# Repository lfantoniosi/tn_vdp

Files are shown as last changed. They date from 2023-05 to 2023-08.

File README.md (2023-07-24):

# TN VDP 

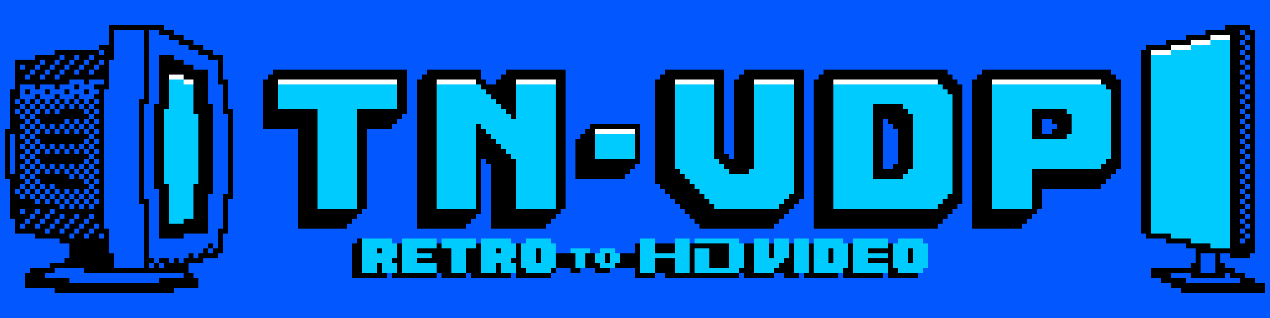
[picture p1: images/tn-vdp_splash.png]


# Latest updates:

## 2023-06-20: V3 Main Board with audio fix (Tang20k only)

New V3 board with audio fix has been submitted. Check the kicad folder for gerbers. It requires few new components that you can read on the board. Pretty simple: 10uf capacitor and an optional cinch connector. I will not be updating the BOM lists. WIP project. For a 9958 socket, turn off GromClk (Jumper 3). Leave CpuClk on (Jumper4).

## 2023-06-20: V9958 Socket (V3 Tang20K)

The V9958 drop-in socket (SDIP-64) has been submitted. Check the kicad folder. Code has been improved for Omega MSX compatibility. SDIP pin header are hard to find. Check AliExpress for **"1.778mm Pitch Single Row Male Round Pin Header"**. Not including links they aren't persistent. You need a V3 main board as well for the Tang20K. 

**Note** My Omega MSX has the RAM expansion module and I found out it has incompatiblity with the Tang (seems to be too noisy). If you get issues with IDE controllers, try removing some RAM chips from higher banks. I left my Omega with only 2MB. It's not a PSU problem but rather a routing issue that plagues the Omega for some time.

# Project details
 
## Tang Nano 9K TMS9118A VDP

This project recreates the TMS9118A (and its TMS9928A/TMS9929A
variants) in FPGA using the over the counter Sipeed's Tang Nano 9K
board plus a designed set of boards to be stacked on top where the
TMS9118 was located.

TN VDP v1 uses
[Matthew Haggerty's F18A core](https://github.com/dnotq/f18a), which
is completely compatible with the original Texas Instruments VDP, but
adds
[additional video modes, sprites and color capabilities](https://dnotq.io/f18a/intro.html).

The bitstream file is [here](fpga/tn_vdp_v1/impl/pnr/tn_vdp.fs)

## Version 2.0

The new version supports audio over HDMI. There is no more VGA output. You'll need to pull the pre-amplified audio from somewhere in the computer and connect the **AUDIO** pin on the tn-vdp socket. **MODE1** is not used for TMS9918 cores.

This requires the v2 board sets as well the v2 bitstream (socket board + mainboard). See below gerber files.

There are 2 bitstreams for v2:

[TMS9918](fpga/tn_vdp_v2_v9918/impl/pnr/tn_vdp.fs)

## V9958 32KB VRAM

There is a new core for the v2 boards implemented from ESE-MSX3. The bitstream can be used on the same v2 board sets for the TMS9918:

[V9958](fpga/tn_vdp_v2_v9958/impl/pnr/tn_vdp_v9958.fs)

But for the V9958 you need to pull the A1 address line from somewhere in the computer and connect to pin **MODE1** on the socket to use the full capabilites of the V9958.

## V9958 128KB VRAM: Tang Nano 20K

The v3 of the fpga code and mainboard is for use on a Tang Nano 20K only. There are no other versions for Tang Nano 20K other than V9958 128K. If you need a 9918 use the Tang Nano 9K instead. The socket for the TMS9118 is the same from v2. A socket for a V9958 replacement is in the works.

See instructions below for programming it.

**Note** The gromclk signal has been retired from V9958 128K (no MSX ever uses it). So instead turning this jumper on puts the VDP in no-wait mode, full speed 27Mhz. Turning off it makes the VDP at normal speed (for VDP commands).

## NABU PC Floppy images

Bootable 80 colums for NABU PC CP/M 3 images can be downloaded here (flux and HxC2001): 

[NABU PC images](https://drive.google.com/file/d/1nU48-01ozhA_n-ZHN1SCNINqFqhcBxUN/view?usp=sharing)

## Gerber files

The gerber files can be located inside each KiCad project:

### V1 Boards
[MainBoard for NABU](kicad/tn_vdp_v1_slim/gerber.zip)

[MainBoard for TI-99/4A (FAT)](kicad/tn_vdp_v1_fat/gerber.zip)

[VGA breakout](kicad/tn_vdp_v1_vga/gerber)

[Compact board using SMD components](kicad/tn9k_f18a_compact/gerber.zip)
See the [separate README](kicad/tn9k_f18a_compact/README.md) for BOM ipand additional information.

The VGA module is optional, only if you want VGA output.

### V2 Boards

[MainBoard v2](kicad/tn_vdp_v2_board/gerber.zip)

[Socket v2](kicad/tn_vdp_v2_socket/gerber.zip)

### V3 Boards: Tang Nano 20K ONLY!

[MainBoard v3](kicad/tn_vdp_v3_board/gerber.zip)

[Socket v2](kicad/tn_vdp_v2_socket/gerber.zip) (same TMS9918 socket as v2)

## Gowin IDE
Follow this link to install the Gowin's IDE:

**Note: The code can be built and programmed using the latest Education Version 1.9.8.11 - The Education EDA does not require a license. DO NOT USE THE BETA EDA/PROGRAMMER.**

[IDE Installation](https://wiki.sipeed.com/hardware/en/tang/Tang-Nano-Doc/install-the-ide.html)

The FPGA series is GW1NR and the Device is GW1NR-9C. Use Embedded Flash Mode for permanent programming. Make sure the bitstream is set to Load Rate of 25Mhz (or higher) in the Project -> Configuration -> BitStream: Loading Rate (MHZ). The maximum for this device is 25 Mhz.

## Programming the FPGA

**Gowin Programmer**
Together Gowin IDE you find the programmer or you can install the programmer stand alone. Check the Gowin IDE instructions

**openFPGALoader**
Alternatively you can use the openFPGALoader but it requires changing the FTDI drivers through zadig. Follow the official page for instructions

The [openFPGALoader](https://github.com/trabucayre/openFPGALoader)
tool can be used to program the FPGA from the command line.

```
sudo openFPGALoader -b tangnano9k tn_vdp.fs
```

## Standalone test

The board has a standalone boot screen when you connect it to the USB-C and HDMI only. This will tell the FPGA has been programmed with success.

The v3 Tang Nano 20K has no standalone boot screen.

## Building:

The Tang Nano 9K board can be purchased on AliExpress or ebay.

The boards gerber files are inside each kicad project gerber folders.

## V1 BOM

The BOM for the NABU and FAT v1 variants can be found here [DigiKey BOM](https://www.digikey.ca/short/2t98zrjw)

Or transcribed here
```
Qty | Part Number                | Description
----+----------------------------+----------------------------------
1x  | 123-A-HDF15A-KG-TAXB-ND    | CONN D-SUB HD RCPT 15P R/A SLDR
3x  | 123-AR20-HZL-TT-ND         | CONN IC DIP SOCKET 20POS TIN
2x  | S7022-ND                   | CONN HDR 24POS 0.1 TIN PCB
1x  | 449-KT04RTH-ND             | SWITCH SLIDE DIP 4POS 25MA 24V
3x  | 296-8503-5-ND              | IC TXRX NON-INVERT 3.6V 20DIP
3x  | 1109PHCT-ND CAP            | CER 0.1UF 50V X7R AXIAL
2x  | 2057-PH2RA-16-UA-ND        | CONN HEADER R/A 16POS 2.54MM
2x  | A835AR-ND                  | CONN HDR DIP POST 20POS GOLD
1x  | ED3048-5-ND                | CONN IC DIP SOCKET 40POS TIN
1x  | 2057-ICM-640-1-GT-HT-ND    | MACHINE PIN SOCKET, IC, DIP, 40P
1x  | 1528-5294-ND               | GPIO RIBBON CABLE 2X10 IDC CABLE
3x  | CF14JT2K20CT-ND            | RES 2.2K OHM 5% 1/4W AXIAL
2x  | CF14JT47R0CT-ND            | RES 47 OHM 5% 1/4W AXIAL
3x  | CF14JT4K70CT-ND            | RES 4.7K OHM 5% 1/4W AXIAL
3x  | CF14JT1K00CT-ND            | RES 1K OHM 5% 1/4W AXIAL
3x  | F14JT470RCT-ND             | RES 470 OHM 5% 1/4W AXIAL
1x  | 497-4547-1-ND              | DIODE SCHOTTKY 20V 1A DO41
```
**Notes:**

1) CONN HDR DIP POST 20POS GOLD: It is expensive on DigiKey but it can be sourced elsewhere cheaper, even Amazon.
2) GPIO RIBBON CABLE 2X10 IDC CABLE : It was supposed to be 2x8 but is out of stock. The 2x10 just works. Or build your own.
3) The capacitors need to be soldered manually on the bottom of each IC's. There are no pads for them to reduce the size of the board. See back.jpg photo for reference under images folder.
4) There are 2 DIP 40 sockets in this list: one machined other normal. The machined socket you will use to connect the board on top, thus protecting the pins. The machined pins for the board will connect easily to a machined socket. Then you stack this machined socked over the normal one (notice little force is necessary), and then finally you stack them at the NABU PC's TMS9118 socket. This will protect both the NABU and the tn_vdp pins.

# V2 BOM
```
Qty | Part Number                | Description
----+----------------------------+----------------------------------
3x  | 123-AR20-HZL-TT-ND         | CONN IC DIP SOCKET 20POS TIN
1x  | 2057-ICM-308-1-GT-HT-ND    | MACHINE PIN SOCKET, IC, DIP, 8P
3x  | 296-8503-5-ND              | IC TXRX NON-INVERT 3.6V 20DIP
4x  | BC1084CT-ND                | CAP CER 0.1UF 50V X7R RADIAL
1x  | 1528-5294-ND               | GPIO RIBBON CABLE 2X10 IDC CABLE
1x  | 497-4547-1-ND              | DIODE SCHOTTKY 20V 1A DO41
1x  | MCP3202-CI/P-ND            | IC ADC 12BIT SAR 8DIP
2x  | S7022-ND                   | CONN HDR 24POS 0.1 TIN PCB
2x  | A835AR-ND                  | CONN HDR DIP POST 20POS GOLD
4x  | 732-5301-ND                | CONN HEADER VERT 20POS 2.54MM 
1x  | 10129379-920001BLF-ND      | CONN HEADER R/A 20POS 2.54MM
4x  | S9000-ND                   | CONN JUMPER SHORTING TIN
```
**Notes:**

I find these header pins 2.54mm too expensive on DigiKey. I'd advise you to procure them on AliExpress, longer wait time but way cheaper. 

# V3 BOM

The V3 BOM is almost identically to V2 except that I added a trimmer for the audio and I returned with the DIP switch 4 pos:

```
Qty | Part Number                | Description
----+----------------------------+----------------------------------
1x  | 3339P-1-103LF              | TRIMMER 10K OHM 0.5W PC PIN TOP
1x  | 449-KT04RTH-ND             | SWITCH SLIDE DIP 4POS 25MA 24V
```

## Jumper Settings

These are the jumper. Closed means ON:
```
USR1 : SPR MAX - Turn it on for 32 sprites per line (9958 this puts 8 sprites for mode 0)
USR2 : SCANLIN - Turn it on for scanlines
USR3 : GROMCLK - Turn it on to have GROM CLOCK enabled, Disabling it puts CPUCLK on pin 37 (9128/29)
USR4 : CPUCLK  - Turn if on to have CPU CLOCK on pin 38 (9929/29 and 9128/29)
```

## Assembling Instructions

You shouldn't have problem assembling it as all components are labeled. Just remember the 2 pin strips for the TMS9118 slot goes under the board as well the 3 caps. Everything else it on the top side. I personally prefer soldering the female header on the FPGA board. Mind the orientation of the **DIP switch** as the image below.
```
1) solder the 3 DIP-20 sockets on top side
2) for each socket, solder one axial caps under the board connecting pins GND and VCC the back image below
3) solder the mini-switch on top side, mind hte numbering according to the text
4) solder the two male machine strips under the board (20 pins each strip)
5) solder the male pins that came with the Tang Nano 9K board on the top side of the board (24 pins each)
6) solder the 8x2 right angle header (optional for VGA)
6) solder the 2 female headers under the Tang Nano 9K board
7) install the 3 74VLC256 chips. Mind the half-moon orientation
7) plug the Tang Nano 9K on the male pins, mind the HDMI and UBS-C orientation as printed on the board
8) configure the dip-switches
```

## DIP switches
```
USR1 - 32 sprite per line (TMS9918), 8 sprites per line (V9958)
USR2 - scanlines
USR3 - pin 37: gromclk (on), cpuclk (off)
USR4 - pin 38: cpuclk (on), NC (off)

TMS9918A: (NABU-PC, CX5M)
USR3 - on
USR4 - on

TMS9928/29A
USR3 - on
USR4 - off

TMS9918
USR3 - on
USR4 - on

TMS9128/29
USR3 - off
USR4 - off
```

## V3 Programming

The Tang Nano 20K version is a bit more convoluted to install. We need to reconfigure the PLL nets.

First using the programmer flash this LITEX on the board:

[Tang Nano 20K LITEX](fpga/tn_vdp_v3_v9958/res/pnr/tang_nano_20k_litex.fs)

Disconnect and re-connect to your PC.

Go to device manager and change the properties for the USB Serial Port (COMxx) for your Tang Nano 20K (disconnect/reconnect the board and see wich one disappear to identify it). Change the Port Settings: Bits per second to 115200 and Apply.

Now you need a terminal application like Tera Term to connect to serial port.

Pressione Control-X Control-C and ENTER

You should see the LITE terminal, type:

```
pll_clk O0=50M
pll_clk O1=125M
pll_clk -s
```

After that you can just flash the v3 core from here:

[V9958 128K](fpga/tn_vdp_v3_v9918/impl/pnr/tn_vdp_v3_v9958.fs)

Now the board is ready to use.

## Images

Front of the board

You need to solder the capacitors under each IC's. I made this way to reduce the size of the board.

Back of the bard

And the final board stacked up. To avoid plugging the board inverted there are two labels on it: **USB-C SIDE** and **HDMI SIDE**. The orientation of the board towards the TMS9118 slot is the USB-C up (pin 1 of TMS9118). The TMS9118 pin number 1 and 40 are printed under it.

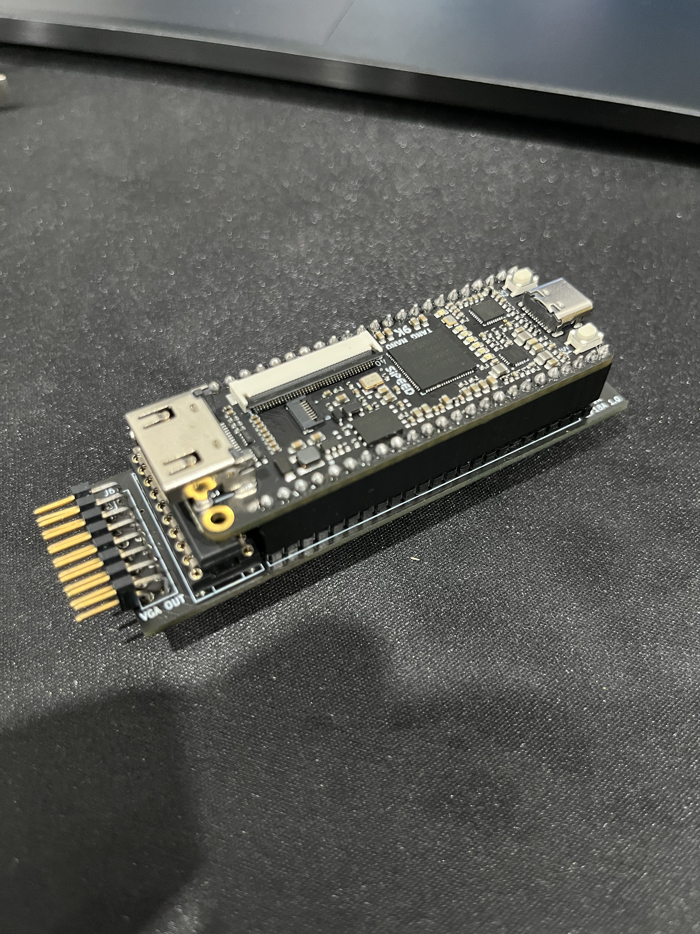
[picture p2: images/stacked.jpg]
Stacked


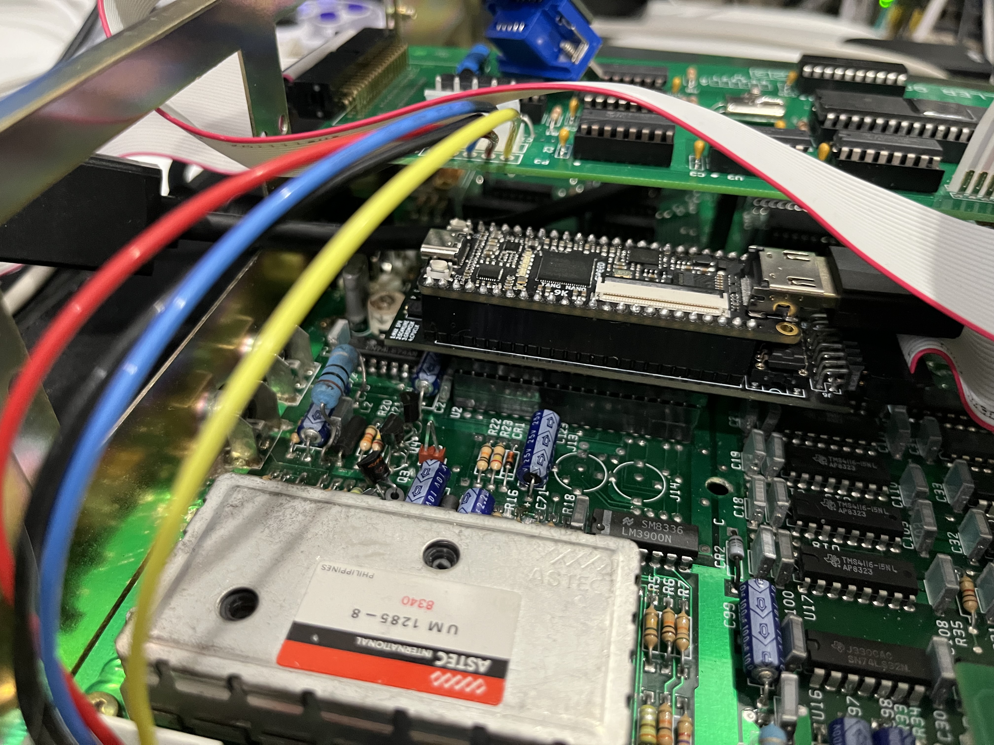
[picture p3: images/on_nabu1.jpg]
On Nabu 1


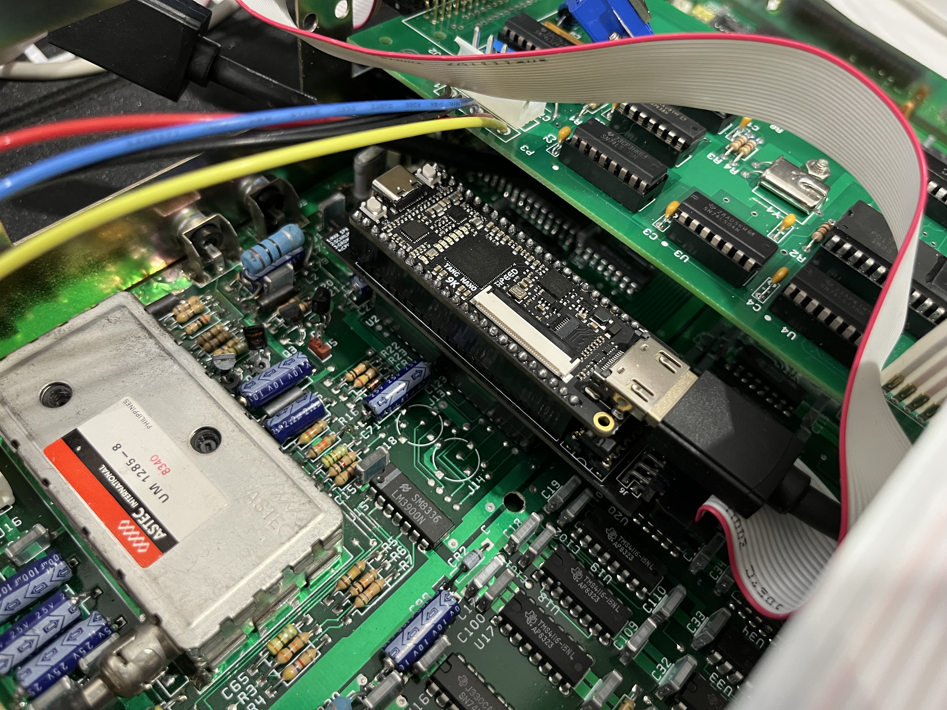
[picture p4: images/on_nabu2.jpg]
On Nabu 2


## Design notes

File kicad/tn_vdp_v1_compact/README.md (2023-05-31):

# TMS9918A compatible VDP based on Tang Nano 9k - Compact (SMD) version

This version is a compact variant of the tn_vdp_v1 board that directly
fits into the VDP socket of the TI-99/4A.  It uses SMD components and
has the same size as the Tang Nano 9k board.  It comes with a VGA
breakout connector that can be directly used if the space in the host
machine allows it, or be snapped off, mounted on a breakout panel on
the back of the host machine and be connected with a ribbon cable.

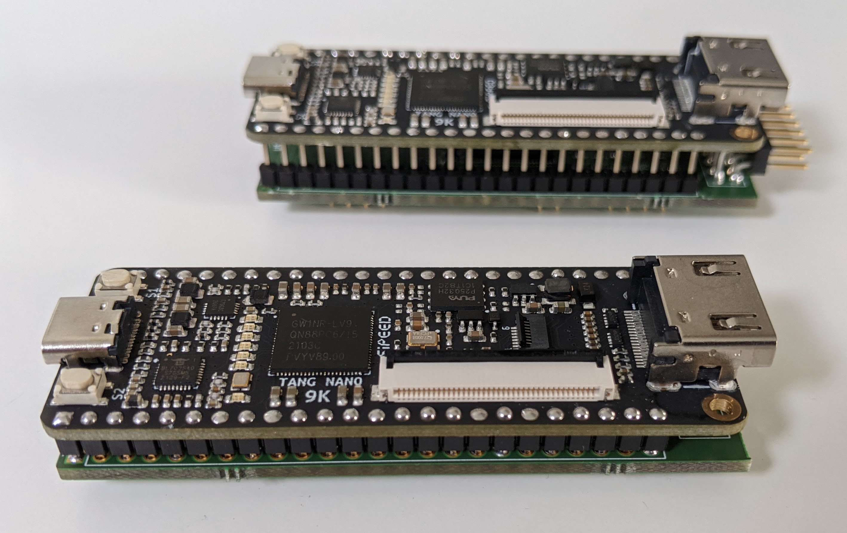
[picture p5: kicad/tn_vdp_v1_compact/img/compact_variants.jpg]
Two variants of the compact board

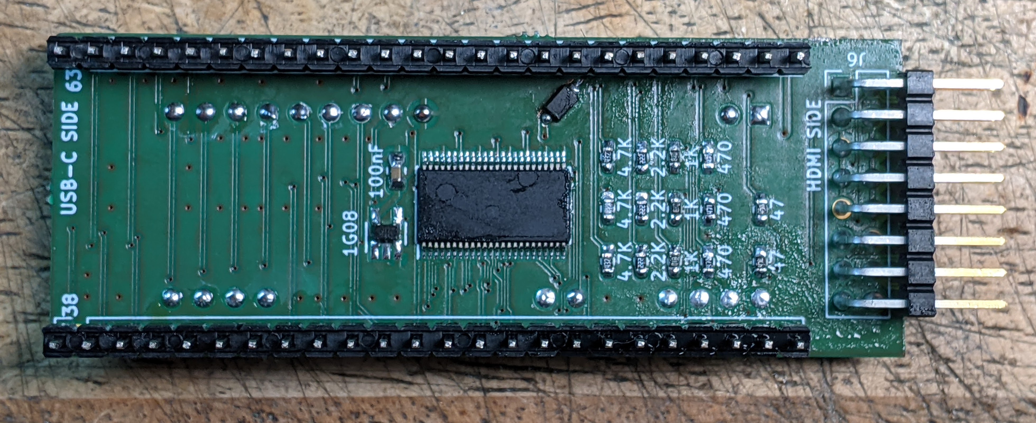
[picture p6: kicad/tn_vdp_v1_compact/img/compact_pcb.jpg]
Compact PCB


## BOM

|Item|Qty|Reference(s)|Value |Description |Part Number |Footprint|URL |
|----|---|---|---|---|---|---|---|
|1 |1  | |Tang Nano 9k|FPGA development board | | |https://wiki.sipeed.com/hardware/en/tang/Tang-Nano-9K/Nano-9K.html|
|2 |1  |U1 |1G08 |Single AND gate |SN74LVC1G08 |SOT-23-5 |http://www.ti.com/lit/sg/scyt129e/scyt129e.pdf |
|3 |1  |U4 |74LCX16245  |16 bit buffer |74LCX16245MTD |TSSOP-48 |https://www.onsemi.com/pdf/datasheet/mc74lcx16245-d.pdf |
|4 |1  |D1 |D_Schottky  |Schottky diode |MBR0530 |SOD-123  | |
|5 |3  |R1, R5, R9  |4.7K |Resistor SMD 0603 | |0603 | |
|6 |3  |R2, R6, R10 |2.2K |Resistor SMD 0603 | |0603 | |
|7 |3  |R3, R7, R11 |1K |Resistor SMD 0603 | |0603 | |
|8 |3  |R4, R8, R12 |470 |Resistor SMD 0603 | |0603 | |
|9 |2  |R13, R14 |47 |Resistor SMD 0603 | |0603 | |
|10  |1  |C1 |100nF |Capacitor SMD 0603 | |0603 | |
|11  |21 |J1 | |PCB pin Mill-Max |3157-0-00-15-00-00-03-0| | |
|12  |1  |J6 |VGA |Pin Header 2.54mm Horizontal 16pos |68021-116HLF | | |
|13  |1  |J2 |VGA |Ribbon cable 16 pin 2x8 solder to 2x8 IDC| | |https://de.aliexpress.com/item/1005004165880347.html |
|14  |1  |J5 |VGA |DB15HD connector, female | | | |

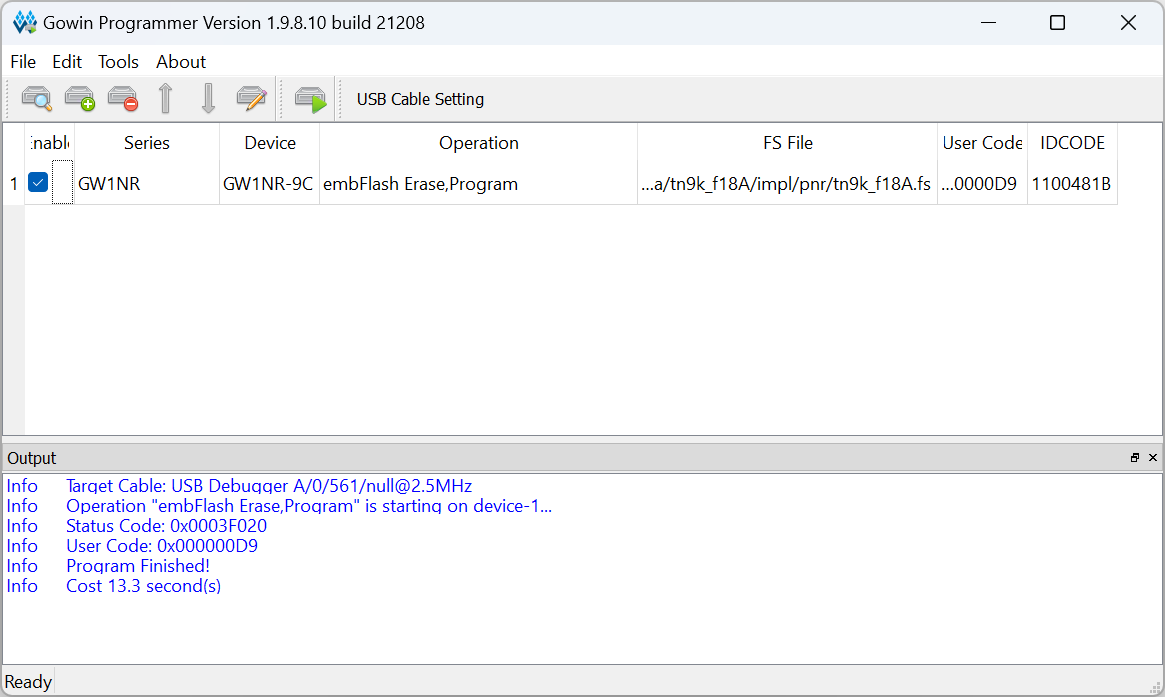
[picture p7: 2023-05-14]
images/programmer.png

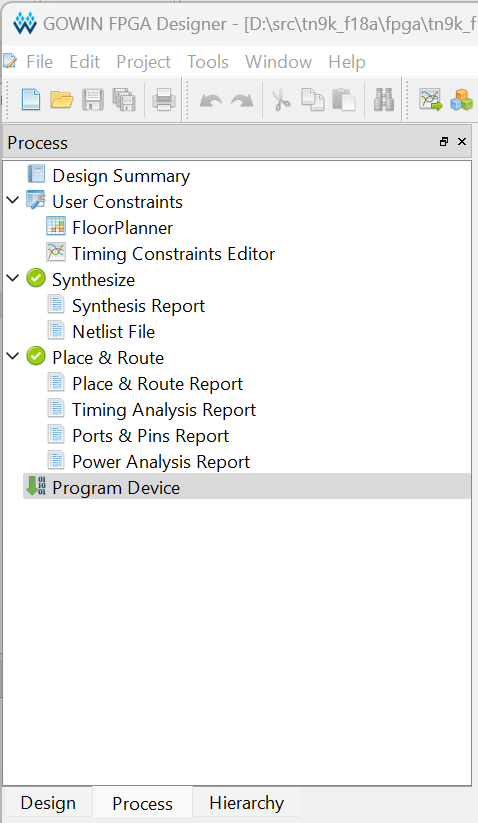
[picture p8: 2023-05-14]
images/program-device.png

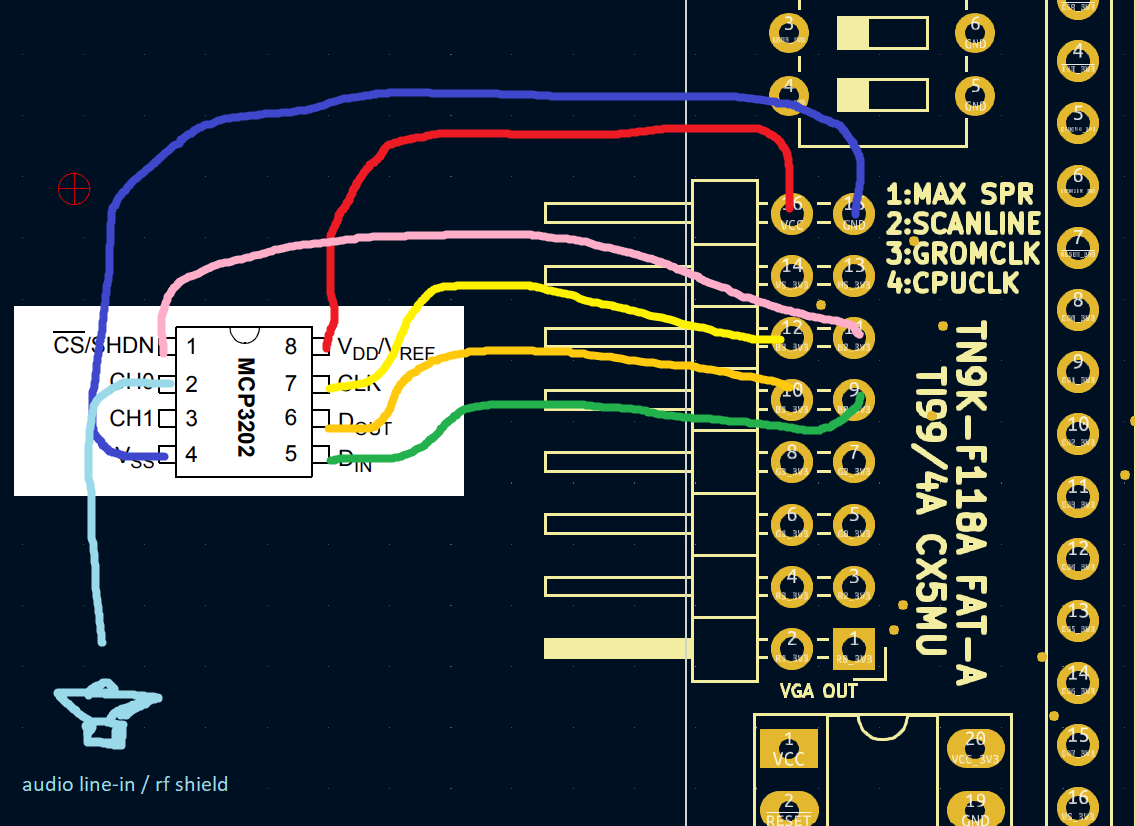
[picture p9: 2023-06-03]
images/audio_modification_fat_board.png

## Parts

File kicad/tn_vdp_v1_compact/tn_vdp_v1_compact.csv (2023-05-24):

Comment | Designator | Footprint | LCSC
100nF | C1 | Capacitor_SMD:C_0603_1608Metric_Pad1.08x0.95mm_HandSolder | C2857981
D_Schottky | D1 | Diode_SMD:D_SOD-123 | C2900723
VGA | J2,J6 | Connector_PinHeader_2.54mm:PinHeader_2x08_P2.54mm_Vertical
Tang Nano 9k | J3 | Connector_PinSocket_2.54mm:PinSocket_1x24_P2.54mm_Vertical
TN9k/2 | J4 | Connector_PinSocket_2.54mm:PinSocket_1x24_P2.54mm_Vertical
VGA | J5 | Connector_Dsub:DSUB-15-HD_Female_Horizontal_P2.29x1.98mm_EdgePinOffset3.03mm_Housed_MountingHolesOffset4.94mm
4.42K | R1,R5,R9 | Resistor_SMD:R_0603_1608Metric_Pad0.98x0.95mm_HandSolder | C5140130
47 | R13,R14 | Resistor_SMD:R_0603_1608Metric_Pad0.98x0.95mm_HandSolder | C3016437
2.2K | R2,R6,R10 | Resistor_SMD:R_0603_1608Metric_Pad0.98x0.95mm_HandSolder | C3016472
1K | R3,R7,R11 | Resistor_SMD:R_0603_1608Metric_Pad0.98x0.95mm_HandSolder | C3016283
470 | R4,R8,R12 | Resistor_SMD:R_0603_1608Metric_Pad0.98x0.95mm_HandSolder | C103660
1G08 | U1 | Package_TO_SOT_SMD:SOT-23-5_HandSoldering | C7666
74LCX16245 | U4 | Package_SO:TSSOP-48_6.1x12.5mm_P0.5mm | C894789

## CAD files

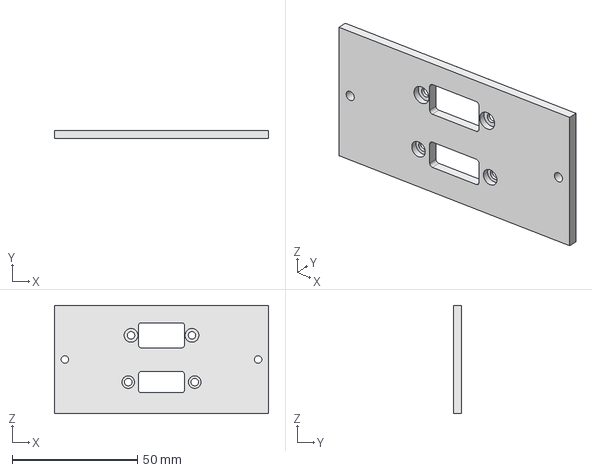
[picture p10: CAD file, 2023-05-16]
models/nabu-backplate.FCStd
85.3 x 3.00 x 43.2 mm

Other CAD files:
models/nabu-backplate.stl

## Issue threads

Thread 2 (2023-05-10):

SMD version?

meup, 2023-05-10:
I have an MSX computer that I don't think has a lot of vertical space above the 9918A (motherboard is below keyboard).
Would you be able to design an SMD version (for the 245 IC's & decoupling caps) that requires less height?
Maybe also a FPC connector for the VGA port might help, and I believe there are SMD DIP switches as well.
I notice that the 74LVC245 comes in many possible packages; the "SO" type seems a reasonable size for hand soldering.

hanshuebner, 2023-05-10:
I have done an SMD version in [my fork](https://github.com/hanshuebner/tn9k_f18a/tree/compact) - It looks about like this:

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

It does not currently have configuration switches as I believe that solder jumpers will be adequate for most use cases, but maybe I'll have some on the next revision.  Likewise for the FPC connector - I've gone for the snap-off part for now, but if there is enough demand, replacing the IDC footprint by an FPC footprint won't be hard.

The DIP-40 pins are shifted slightly to one side to accommodate the space available in the TI-99/4A.  I've got a couple of boards on order and will open a PR once I have tested them and verified that they work.

lfantoniosi, 2023-05-12:
Hans answered

Closed 2023-05-12.

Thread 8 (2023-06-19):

32K limit for V9958?

HeathenUK, 2023-06-19:
Hi there,

Amazing work, congratulations!

Am I right in thinking that the limiting factor on "VRAM" for the V9958 gateware is the amount of SRAM or BRAM available on the TN9K?

If so - and recognising that you're not targeting this board (yet) - is it possible to create a version with substantially more "VRAM" on the TN20K given the significantly increased on-chip SRAM etc.? I can only assume it's not as easy as increasing reg [7:0] mem_r[0:32767];r to reg [7:0] mem_r[0:131068];

In any case I'm hoping to get a build going on the TN20K of the current source.

Regards,

Greg

lfantoniosi, 2023-06-19:
https://www.youtube.com/watch?v=Je3N2BwWwb8&lc=

Closed 2023-06-19.

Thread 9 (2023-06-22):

V9958 TN20k

lintweaker, 2023-06-22:
First off, great work!
I was about the create an issue regarding porting V9958 32k to the Tang Nano 20k. I saw your video showing this version from 3d days ago, great stuff!
So basically just 2 questions:
- are you planning to release that code?
- Are you using the integrated SDR SRAM for the VRAM?
Thx.

HeathenUK, 2023-06-22:
And to add a related question - I was going to pick up the existing socket design (which fits the TMS9918 DIP40) and create a V9938/58 version, unless that's cutting across something already planned?

lfantoniosi, 2023-06-22:
the 9958 version is planned. A 9938 is not exact pin compatible. I still did not finish the 9918 version, don't rush pls.

I don't know the signals I need to generate or read.  it will be good for omega msx but hell no I am not removing a9958/9938 from my MSX2/2+/Tr computers,

Also the SDIP pin headers are non-existent in North America suppliers. I had to get from Ali-express and they are not the cheapest.

lfantoniosi, 2023-06-22:
This should answer any question: https://www.youtube.com/watch?v=Je3N2BwWwb8&t

HeathenUK, 2023-06-22:
Yeah, it's for my OmegaMSX I'm thinking of.

G

Closed 2023-06-22.

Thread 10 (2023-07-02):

tn_vdp_v3_v9958 aux pll config

lintweaker, 2023-07-02:
Hi,
Thanks for v3 v9958!
Possible issue with the docs regarding programming the Aux PLL
The constraint file states:

IO_LOC "clk_50" 10;       // crystal<br>
IO_LOC "clk_125" 11;       // crystal<br>
IO_LOC "clk_63" 13;       // crystal<br>
`
The Tang 20k schematic shows:
`
CLK0 - PIN10
CLK1 - PIN11
CLK2 - PIN13
`
So, the Aux PLL should be set via:
`
pll_clk O0=50M
pll_clk O1=125M
pll_clk -s
`
?
Thanks.

lfantoniosi, 2023-07-02:
yeah you are right. updating the docs

Closed 2023-07-07.

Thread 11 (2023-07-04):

Purpose of the diode

leonkiriliuk, 2023-07-04:
Can you please add a note in the README for the purpose of the diode? I managed to figure it out due to help from someone on Discord, but many like me that found this repo via your YT channel will not know what to do with the diode (especially for V1 PCBs)

AxelAhlborn, 2023-08-04:
You can find a photo here: https://forums.nabu.ca/download/file.php?id=181&mode=view
Note that the line on the board between the two PINs must be separated.

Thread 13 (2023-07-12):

Go Win Programmer Error

AxelAhlborn, 2023-07-12:
Hi,
installed GoWin IDE Education 1.9.8.11 Build 21024
Use GoWin Programmer
Series GW1NR, Device GW1NR-9C Embedded Flash Mode Erase, Program, Verify
File E:/Tools/tn9k/tn_vdp.fs

Output of Gowin Programmer:
  Info:	Cable found:  USB Debugger A/0/545/null (USB location:545)
Info:	Cost 0.56 second(s)
:
Info:	Target Cable: USB Debugger A/0/545/null@2.5MHz
Info:	Operation "embFlash Erase,Program,Verify" is starting on device-1...
Error:	Verify Failed at 0
Error:	Verify Failed!
Info:	Cost 10.84 second(s)
:

Need some help 😇

Greetings Axel

lfantoniosi, 2023-07-12:
Did you choose flash generic? If so check:

Reboot pc
Re-install drivers
Check usb cable

There sre so many things

On Wed, Jul 12, 2023 at 5:40 AM AxelAhlborn ***@***.***>
wrote:

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
--
Luis Felipe Antoniosi

lfantoniosi, 2023-07-12:
Which one? Tang 20k has no test screeb

On Wed, Jul 12, 2023 at 8:30 AM AxelAhlborn ***@***.***>
wrote:

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
--
Luis Felipe Antoniosi

lfantoniosi, 2023-07-12:
Dont verify i don’t verify either.

Check sipeed website for usb issues. It can’t help you here i had once to
delete every trace of ftdi drivers in my win 11. Try a fresh new
installation.

Also it does not work from virtual machines. Very picky.

On Wed, Jul 12, 2023 at 8:30 AM AxelAhlborn ***@***.***>
wrote:

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
--
Luis Felipe Antoniosi

AxelAhlborn, 2023-07-13:
That's OK. I use the tn9k with tn vdp V1. The problem I have with this is that I don't know if the flash was successful or not because the TN9K has the R1 bridge problem over HDMI. If the bridge is not set, some HDMI devices cannot display a picture. So I don't know if it's one thing or the other. I will create the vga board to test with vga.
Greetings Axel

Closed 2023-07-13.

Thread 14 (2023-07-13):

TI-99/4A

shift838, 2023-07-13:
Which gerbers are specifically for the 99/4A, only the FAT model version 1?  or will any of the others work.  Please specify so I know which one(s) to order.

Thanks

AxelAhlborn, 2023-08-03:
Maybe this will help
https://github.com/lfantoniosi/tn_vdp/issues/2

I still have one board V1 TI99 left. If you are interested, please let me know.

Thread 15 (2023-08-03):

Problems with VGA breakout VGA socket

AxelAhlborn, 2023-08-03:
The holes for the VGA socket are too close together. The distance between the first and the last row is 4mm. It should be about 5mm. See also https://cdn-reichelt.de/documents/datenblatt/C120/DS_DSUB_HD_FWP.pdf

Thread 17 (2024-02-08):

Confusing V3 board / socket; photo for a fully assembled one

arm1969, 2024-02-08:
Would you please add a photo for a fully assembled board + socket of V3? Another with the board installed on Nabu (with audio) would be wonderful.

It is not clear as I can see 2 IDC connectors and not sure where all the parts should go (headers specifically). The socket schematics seems confusing (not sure which for which). There is also 4 jumpers mentioned in the BOM .. where do these go? Main board or socket!!

I do apologize if I sound like a lame person but your project will give life to my Nabu in a way I have never imagined. Thank you for all the hard work. This is really an amazing thing for the Nabu.

zomgugoff, 2024-08-22:
Looking at the traces using PCBWay's gerber viewer, the IDC headers are wired to each other. I would guess they allow for putting the headers where they'll physically fit if there are clearance issues.

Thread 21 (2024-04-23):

Not an issue - just a Thank you

dinoboards, 2024-04-23:
Hello,

Just wanted to reach out and say hello.  Your work here has inspired me.  I have forked your project and made a
board for my Yellow MSX DIY Kit series (an RC2014 compatible retro kit computing platform).

My design is a little different than yours, as instead of building a chip replacement module, I designed my module
to insert into my system's backplane - this gives me the ability to connect to any of the Z80 bus signals.  I updated the code to
enable the TangNano to do its own IO decoding onboard.

My repo is at: https://github.com/dinoboards/V9958-Super

There are also a few other things I ended up changing from your design.

1. The output of the INT signal.

I noticed you had a recent commit, to make the INT output tri-state.  But I am not sure how that works, As the INT signal is buffered through a 74LVC245.  Would that not cause the INT signal to float?

For my design, I sent the INT signal to a 74HC32 to get the logic level raised to 5V.  With a diode to simulate an open-drain connection.  Not sure the 74HC32 is required, but I had a spare gate so I just used it.

2. Used one interface 74LVC245 chip for the data bus.  I used the bi-directional nature of this chip to switch from reading to writing.  I haven't detected any bus contention issues.

I do note, that the data out levels are still only at the 3V3 levels and not raised to 5V - it works, but I do wonder about tolerances for people with different kit configurations.

3. Issue with Passive HDMI to VGA converters

I found it initially didn't work for my setup.  I had a passive HDMI to VGA converter, and the system refused to produce an image.  If I disabled the audio signal code, it started to work.  As I barely understand how HDMI works - I can only guess its something to do with the negotiation processes. If the audio logic was enabled, then it would only work on a proper HDMI monitor  (with the audio delivered to the internal speaker)

For my kit, I have a jumper to enable switching AUDIO logic on or off.

4. Converted all the code to Verilog.

As I am totally new to Verilog and VHDL - decided to have a go at converting the VHDL code to Verilog - save me being overwhelmed with learning 2 hardware description languages.  I found some automated tools and for the most part that seemed to convert just fine.

5. Refactored a lot of the code

Once converted to Verilog, I started to try and understand and figure out all the code.  And then I started to refactor and hopefully better suit it for my goals and design.

6. Added some new graphics modes

I have started to add some new graphics mode.  Been patching my MSX-BASIC ROMS to support new screen modes.  This has been a challenge!

7. Learnt what a timing violation is

Boy did I learn --- did I mention I was new to hardware description languages.  Was getting lots of strange errors.  Change a bit of the code, and something unrelated would break.  I kind of expected the Geowin tool chain would 'error' if the design could not be routed correctly.  I figured all this out the hard way.  Created a 'build.sh' script to help me avoid that from happening again.  Still a lot to learn here though.

Anyway,

Just want to say thanks - I have learnt a lot from your project - (I've strived to keep all the copyright/license and attribute all the work you and other have done.)

My stuff is still under development - waiting for the next PCB design to arrive that hopefully has all my remaining little issues ironed out.

Cheers
Dean

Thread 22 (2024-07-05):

Can't compile FPGA for tn_vdp_v2_v9918 with latest version GoWin V1.9.9.03 Education (64-Bit) build (73833)

wiesl, 2024-07-05:
Hello,

I'm getting the following error:
Parsing netlist file "C:\Users\username\Desktop\tn_vdp\fpga\tn_vdp_v2_v9918\impl\gwsynthesis\tn_vdp.vg" completed
ERROR  (PA2122) : Not support 'mem_r_mem_r_0_0_s'(DPB) WRITE_MODE0 = 2'b10, please change write mode WRITE_MODE0 = 2'b00 or 2'b01.
ERROR  (PA2122) : Not support 'mem_r_mem_r_0_1_s'(DPB) WRITE_MODE0 = 2'b10, please change write mode WRITE_MODE0 = 2'b00 or 2'b01.
ERROR  (PA2122) : Not support 'mem_r_mem_r_0_2_s'(DPB) WRITE_MODE0 = 2'b10, please change write mode WRITE_MODE0 = 2'b00 or 2'b01.
ERROR  (PA2122) : Not support 'mem_r_mem_r_0_3_s'(DPB) WRITE_MODE0 = 2'b10, please change write mode WRITE_MODE0 = 2'b00 or 2'b01.
ERROR  (PA2122) : Not support 'mem_r_mem_r_0_4_s'(DPB) WRITE_MODE0 = 2'b10, please change write mode WRITE_MODE0 = 2'b00 or 2'b01.
ERROR  (PA2122) : Not support 'mem_r_mem_r_0_5_s'(DPB) WRITE_MODE0 = 2'b10, please change write mode WRITE_MODE0 = 2'b00 or 2'b01.
ERROR  (PA2122) : Not support 'mem_r_mem_r_0_6_s'(DPB) WRITE_MODE0 = 2'b10, please change write mode WRITE_MODE0 = 2'b00 or 2'b01.
ERROR  (PA2122) : Not support 'mem_r_mem_r_0_7_s'(DPB) WRITE_MODE0 = 2'b10, please change write mode WRITE_MODE0 = 2'b00 or 2'b01.
ERROR  (PA2122) : Not support 'linebuf1_linebuf1_0_0_s'(DPX9B) WRITE_MODE0 = 2'b10, please change write mode WRITE_MODE0 = 2'b00 or 2'b01.
ERROR  (PA2122) : Not support 'linebuf2_linebuf2_0_0_s'(DPX9B) WRITE_MODE0 = 2'b10, please change write mode WRITE_MODE0 = 2'b00 or 2'b01.
ERROR  (PA2122) : Not support 'colram_colram_0_0_s'(DPB) WRITE_MODE1 = 2'b10, please change write mode WRITE_MODE1 = 2'b00 or 2'b01.
NOTE  (PA0005) : Processing netlist completed with errors

Looks like this is a problem, with a read before write of the dual ported RAM part in newer versions of GoWin. That has been removed according to the release notes. Any way to fix it?

Do you have an older version of GoWin to download?

Didn't try other versions but guess same problem with 9k version.

Some research I already made after using search engines:
Picotiny example fails during Place & Route #19
https://github.com/sipeed/TangNano-9K-example/issues/19
Found it: Tools -> IP Core Generator -> Hard Module -> Memory -> Block Memory -> DPB

MiSTery on Tang Nano
https://www.atari-forum.com/viewtopic.php?t=43080&start=200
The manifestation of this seems to have changed over the various GoWin versions. The current MiSTeryNano synthesizes successful with the latest GoWin 1.9.9 (no beta).
Form Gowin BSRAM & SSRAM User Guide
https://cdn.gowinsemi.com.cn/UG285E.pdf
Read before write in dual port mode was removed.

Bug in Gowin while using Tang Nano 9k?
https://www.reddit.com/r/GowinFPGA/comments/1d1t2to/bug_in_gowin_while_using_tang_nano_9k/
In manual "Gowin BSRAM & SSRAM User Guide" page 6:
`GW1N-9/GW1N-1S/GW1NR-9/GW1NS-4 series does not support dual port mode.`
but Gowin EDA synthesizes and does place and routes `DPB` (dual port block ram) + it is available as an IP (without the "byte addressable" in UI but generated in Verilog)
p.s. I solved my problem by using a combination of BSRAM pROM and SP instead of dual port RAM. Not a resourceful use of block RAM but meets the specs and I couldn't use 100% of it anyway.
That the blocking assignment "fixes" the issue makes sense since the device does not support "Read-Before-Write". Making a blocking assignment points out that write is before read so it does make sense.

Still an issue that Gowin IDE generates a netlist that is not supported. Better would be a message at synthesize and indication of how to fix it.

Picotiny example fails during Place & Route #19
https://github.com/sipeed/TangNano-9K-example/issues/19
https://github.com/sipeed/TangNano-9K-example/commit/c3b795799f23de91982be52db4273a8eea100cdb

https://cdn.gowinsemi.com.cn/SUG550E.pdf chapter 4.2 is what you want to work from.
Changing from asynchronous assign to synchronous solves the problem.

Thnx.

Ciao

This fixes it but I guess it doesn't work anymore:
diff --git a/fpga/tn_vdp_v2_v9918/src/ram16k.v b/fpga/tn_vdp_v2_v9918/src/ram16k.v
index d5aae63..b9b9aa8 100644
--- a/fpga/tn_vdp_v2_v9918/src/ram16k.v
+++ b/fpga/tn_vdp_v2_v9918/src/ram16k.v
@@ -18,8 +18,8 @@ end

     always @(posedge clk) begin

-        dout_r <= mem_r[addr];
-        dout2_r <= mem_r[addr2];
+        //dout_r = mem_r[addr];
+        //dout2_r = mem_r[addr2];
         if (we == 1) begin
             mem_r[addr] <= din;
         end

diff --git a/fpga/tn_vdp_v2_v9918/src/f18a/f18a_color.vhd b/fpga/tn_vdp_v2_v9918/src/f18a/f18a_color.vhd
index ccf3789..f3fe08c 100644
--- a/fpga/tn_vdp_v2_v9918/src/f18a/f18a_color.vhd
+++ b/fpga/tn_vdp_v2_v9918/src/f18a/f18a_color.vhd
@@ -167,7 +167,7 @@ begin
    begin
       if rising_edge(clk) then
          if we1 = '1' then
-            colram(to_integer(unsigned(addr1))) <= din;
+            -- colram(to_integer(unsigned(addr1))) <= din;
          end if;

          -- to the GPU! :-)

diff --git a/fpga/tn_vdp_v2_v9918/src/f18a/f18a_sprites.vhd b/fpga/tn_vdp_v2_v9918/src/f18a/f18a_sprites.vhd
index 275a2af..42d196e 100644
--- a/fpga/tn_vdp_v2_v9918/src/f18a/f18a_sprites.vhd
+++ b/fpga/tn_vdp_v2_v9918/src/f18a/f18a_sprites.vhd
@@ -214,8 +214,8 @@ begin
    process (clk)
    begin
       if rising_edge(clk) then
-         dout1a <= linebuf1(to_integer(unsigned(addr1a)));
-         dout1b <= linebuf1(to_integer(unsigned(addr1b)));
+         --dout1a <= linebuf1(to_integer(unsigned(addr1a)));
+         --dout1b <= linebuf1(to_integer(unsigned(addr1b)));
          if we1 = '1' then
             linebuf1(to_integer(unsigned(addr1a))) <= din;
          end if;
@@ -227,8 +227,8 @@ begin
    process (clk)
    begin
       if rising_edge(clk) then
-         dout2a <= linebuf2(to_integer(unsigned(addr2a)));
-         dout2b <= linebuf2(to_integer(unsigned(addr2b)));
+         --dout2a <= linebuf2(to_integer(unsigned(addr2a)));
+         --dout2b <= linebuf2(to_integer(unsigned(addr2b)));
          if we2 = '1' then
             linebuf2(to_integer(unsigned(addr2a))) <= din;
          end if;

lfantoniosi, 2024-07-05:
https://drive.google.com/file/d/1MZrYlVilrAQ4uBdBiUWKo608pO3RBmkC/view?usp=sharing

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

--
Luis Felipe Antoniosi

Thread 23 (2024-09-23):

74VLC256 or 74LVC245 chips?

ComputerArchitect, 2024-09-23:
The description on GitHub mentions three 74VLC256 chips but that looks like a typo as the board shows 74LVC245 chips.  Can you confirm which ones are correct?

lfantoniosi, 2024-09-23:
Yes its a typo.

Luis Felipe Antoniosi

On Sun, Sep 22, 2024 at 7:25 PM Robert Doerr ***@***.***>
wrote:

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

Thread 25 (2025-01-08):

Confused by choice

DirkS-71, 2025-01-08:
If I just need a drop in replacement for the v9958 on a board that has ram already, what is my choice? All the choices seem to have local ram already on the FPGA.

Thanks

lfantoniosi, 2025-01-08:
You get the v3 with shrink dip64 for the socket.

The tn-vdp uses its own internal memory. There aren’t enough pins to use
external memory

Luis Felipe Antoniosi

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

DirkS-71, 2025-01-08:
Ah, so it will just ignore the external memory 👍

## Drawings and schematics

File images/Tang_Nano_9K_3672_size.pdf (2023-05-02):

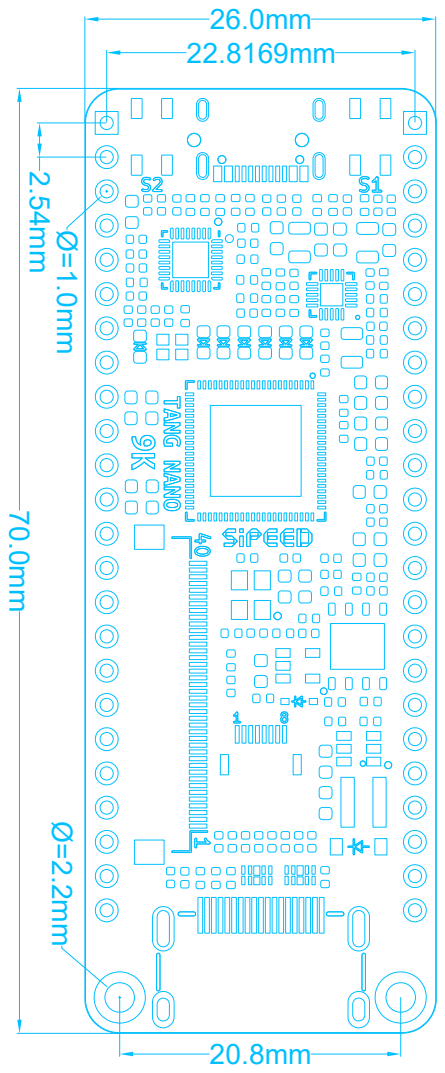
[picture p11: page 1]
26.0mm 22.8169mm 70.0mm ².54mmØ=1.0mm

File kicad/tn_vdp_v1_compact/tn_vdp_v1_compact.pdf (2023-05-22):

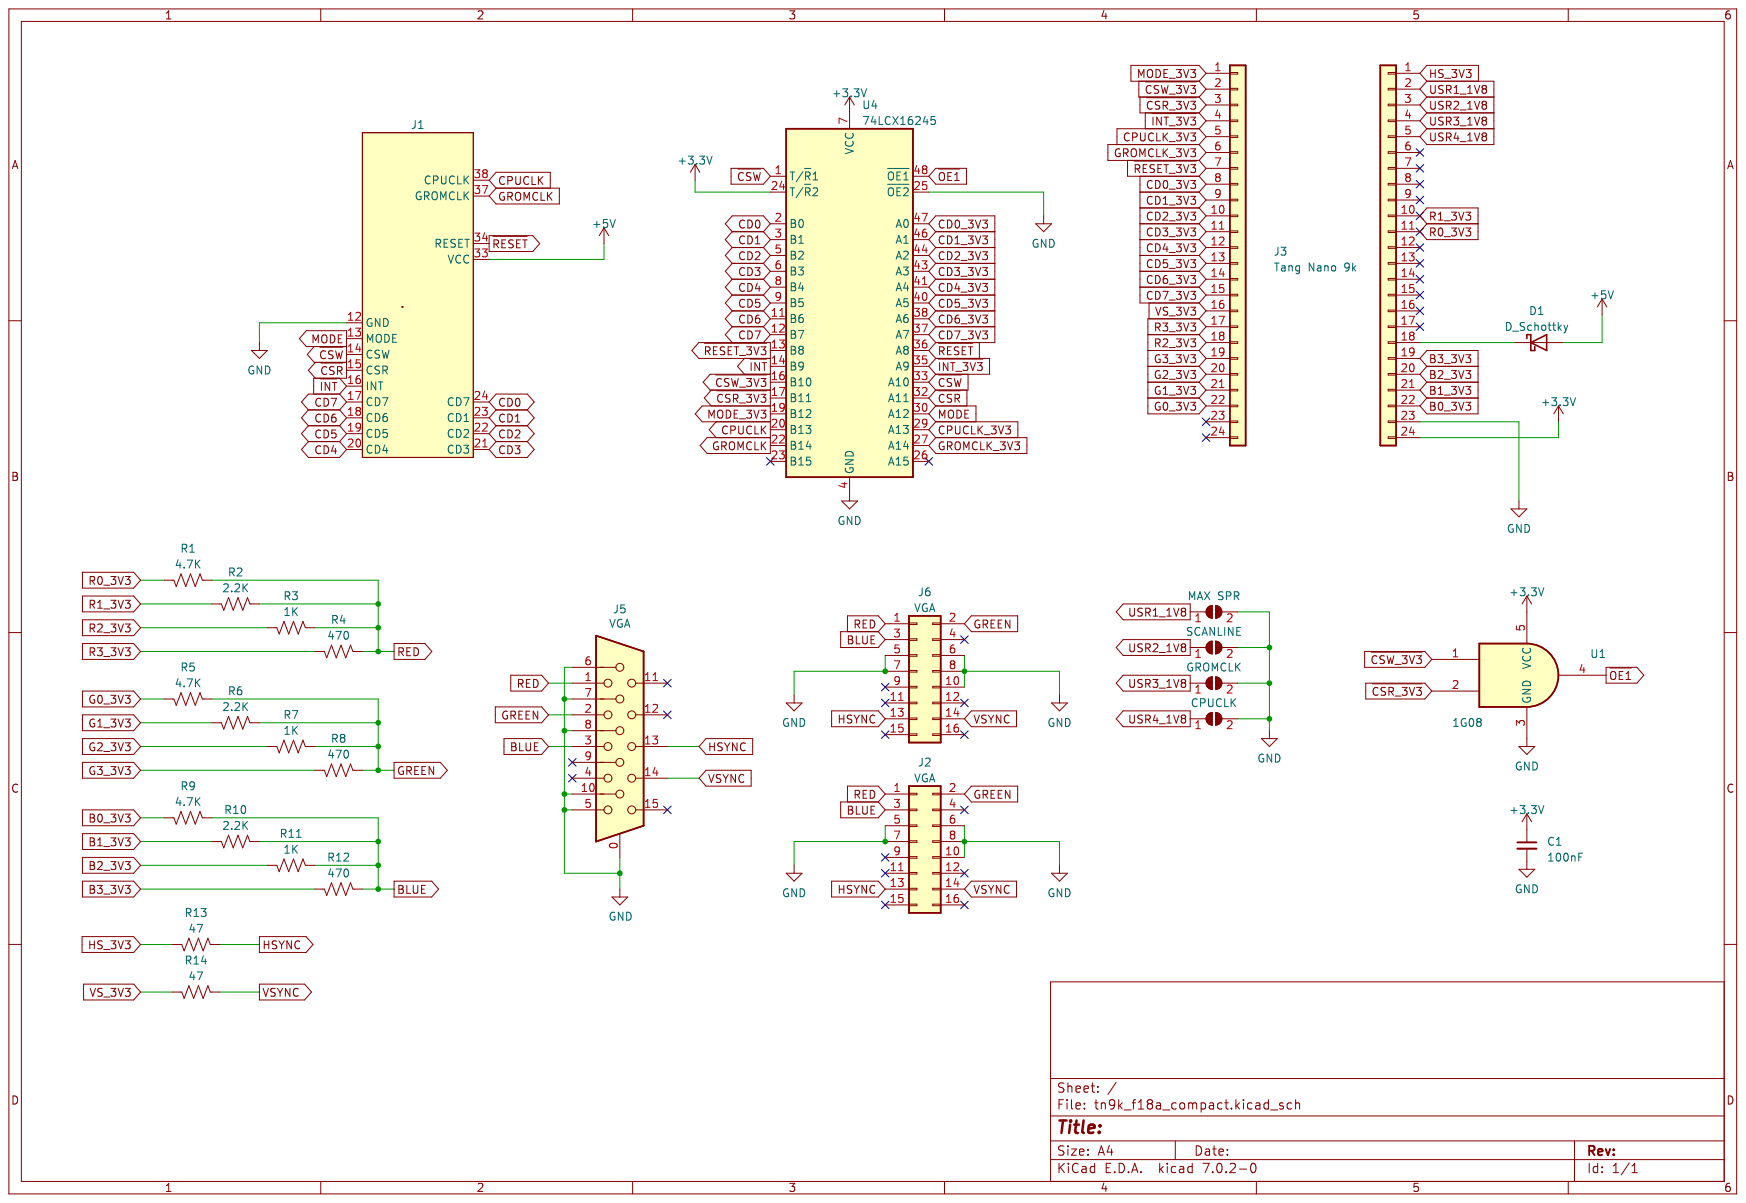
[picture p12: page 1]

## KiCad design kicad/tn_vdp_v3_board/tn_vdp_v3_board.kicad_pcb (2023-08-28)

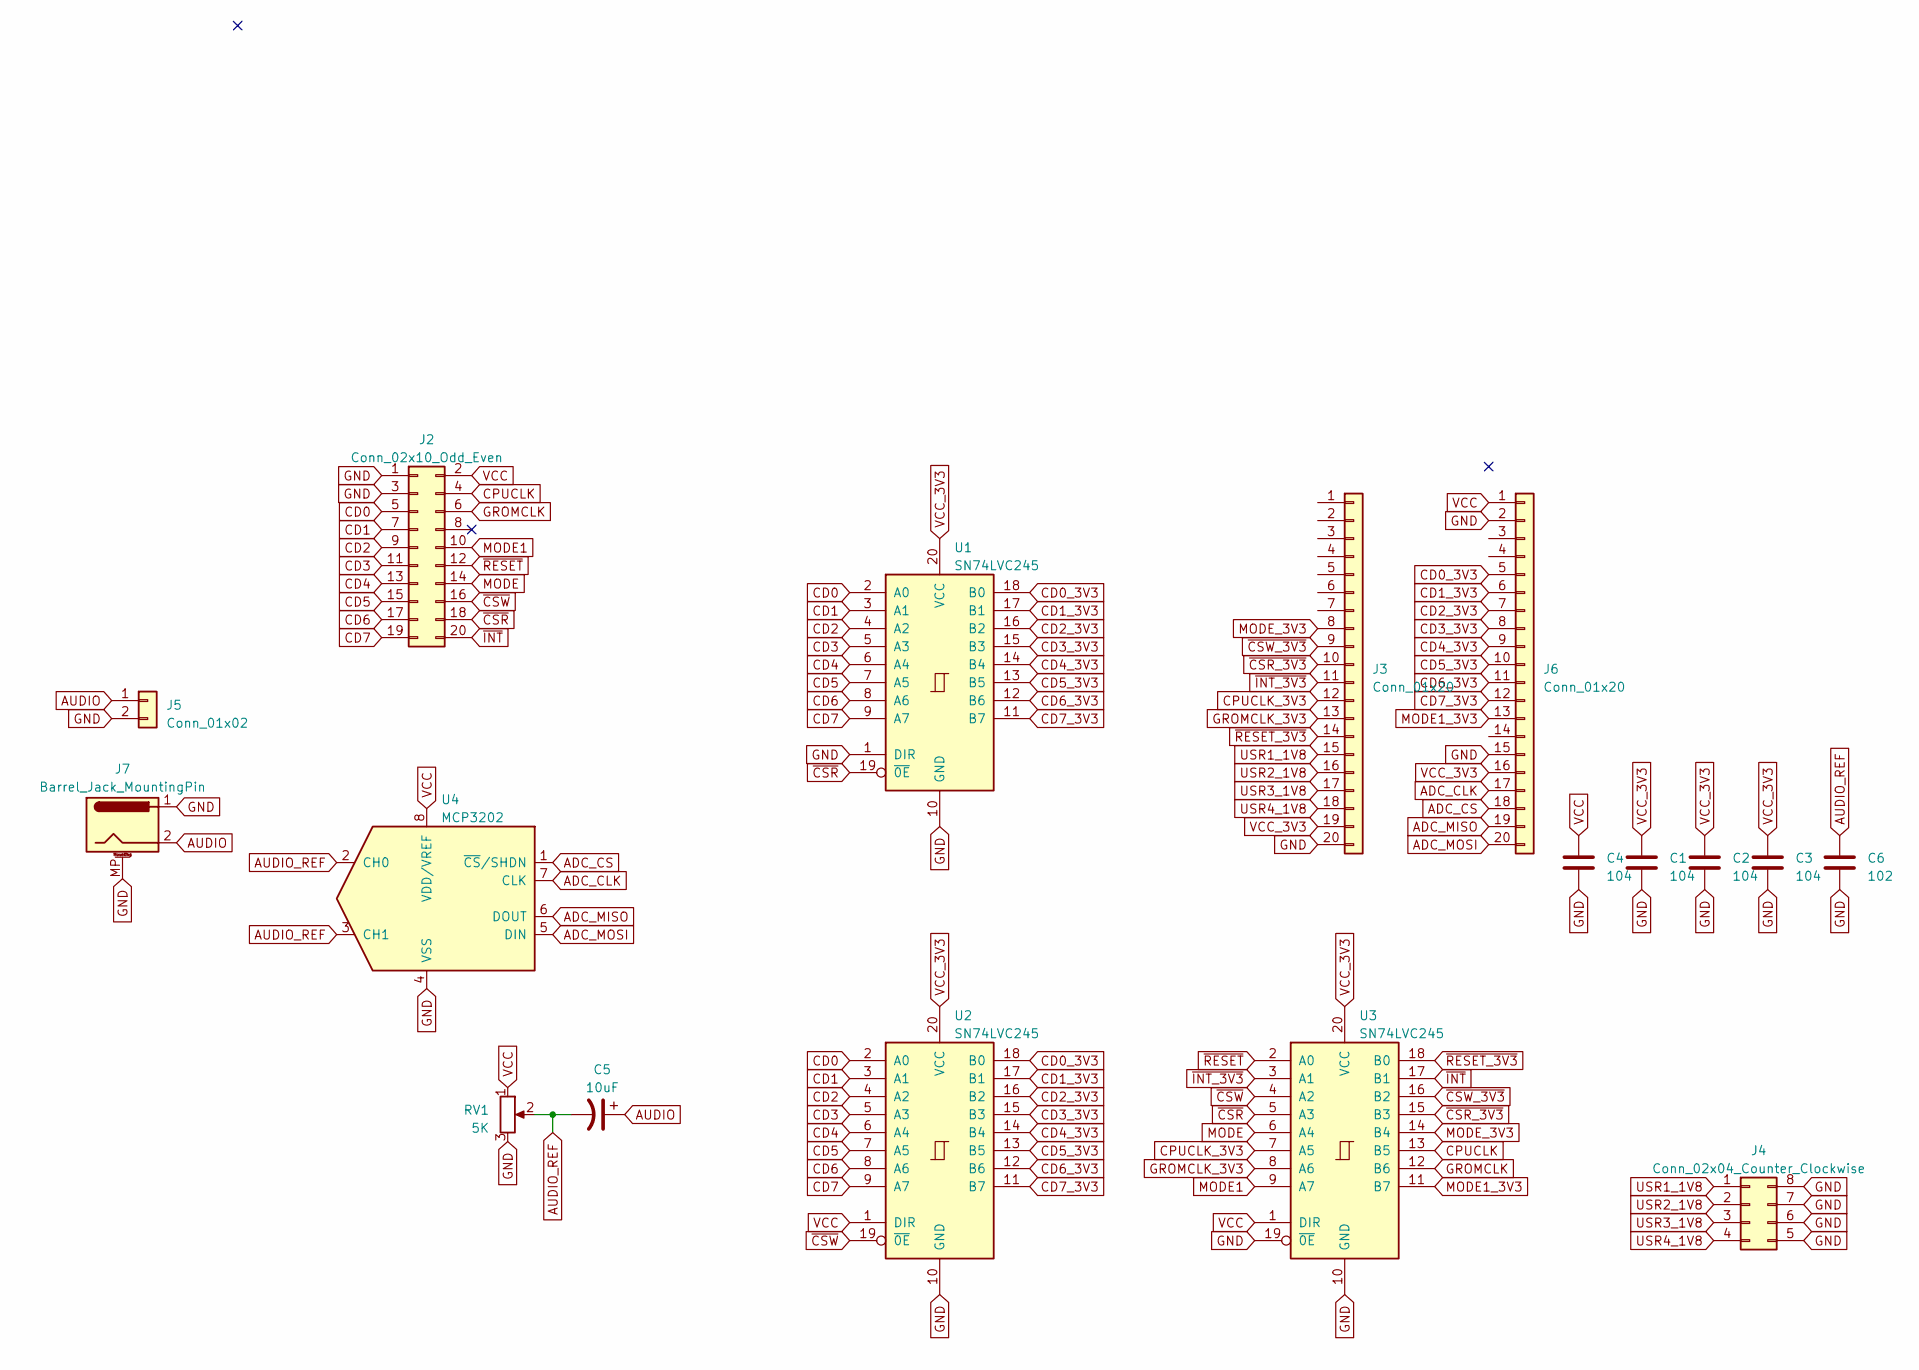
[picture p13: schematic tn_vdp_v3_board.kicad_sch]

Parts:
C1, C2, C3, C4: 104; C_Disc_D5.0mm_W2.5mm_P2.50mm
C5: 10uF; CP_Radial_D5.0mm_P2.50mm
C6: 102; C_Disc_D5.0mm_W2.5mm_P2.50mm
J2: Conn_02x10_Odd_Even; PinHeader_2x10_P2.54mm_Vertical
J3, J6: Conn_01x20; PinHeader_1x20_P2.54mm_Vertical
J4: Conn_02x04_Counter_Clockwise; SW_DIP_SPSTx04_Slide_6.7x11.72mm_W7.62mm_P2.54mm_LowProfile
J5: Conn_01x02; PinHeader_1x02_P2.54mm_Horizontal
J7: Barrel_Jack_MountingPin; BarrelJack_CUI_PJ-063AH_Horizontal_CircularHoles
RV1: 5K; Potentiometer_Piher_PT-6-V_Vertical
U1, U2, U3: SN74LVC245; DIP-20_W7.62mm_Socket_LongPads
U4: MCP3202; DIP-8_W7.62mm_LongPads

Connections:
ADC_CLK: J6.17, U4.7 (CLK)
ADC_CS: J6.18, U4.1 (~CS/SHDN)
ADC_MISO: J6.19, U4.6 (DOUT)
ADC_MOSI: J6.20, U4.5 (DIN)
AUDIO: C5.1, J5.1, J7.2
AUDIO_REF: C5.2, C6.1, RV1.2, U4.2 (CH0), U4.3 (CH1)
CD0: J2.5, U1.2 (A0), U2.2 (A0)
CD0_3V3: J6.5, U1.18 (B0), U2.18 (B0)
CD1: J2.7, U1.3 (A1), U2.3 (A1)
CD1_3V3: J6.6, U1.17 (B1), U2.17 (B1)
CD2: J2.9, U1.4 (A2), U2.4 (A2)
CD2_3V3: J6.7, U1.16 (B2), U2.16 (B2)
CD3: J2.11, U1.5 (A3), U2.5 (A3)
CD3_3V3: J6.8, U1.15 (B3), U2.15 (B3)
CD4: J2.13, U1.6 (A4), U2.6 (A4)
CD4_3V3: J6.9, U1.14 (B4), U2.14 (B4)
CD5: J2.15, U1.7 (A5), U2.7 (A5)
CD5_3V3: J6.10, U1.13 (B5), U2.13 (B5)
CD6: J2.17, U1.8 (A6), U2.8 (A6)
CD6_3V3: J6.11, U1.12 (B6), U2.12 (B6)
CD7: J2.19, U1.9 (A7), U2.9 (A7)
CD7_3V3: J6.12, U1.11 (B7), U2.11 (B7)
CPUCLK: J2.4, U3.13 (B5)
CPUCLK_3V3: J3.12, U3.7 (A5)
GND: C1.2, C2.2, C3.2, C4.2, C6.2, J2.1, J2.3, J3.20, J4.5, J4.6, J4.7, J4.8, J5.2, J6.2, J6.15, J7.1, J7.MP (MountPin), RV1.3, U1.1 (DIR), U1.10 (GND), U2.10 (GND), U3.10 (GND), U3.19 (~0E), U4.4 (VSS)
GROMCLK: J2.6, U3.12 (B6)
GROMCLK_3V3: J3.13, U3.8 (A6)
MODE: J2.14, U3.6 (A4)
MODE1: J2.10, U3.9 (A7)
MODE1_3V3: J6.13, U3.11 (B7)
MODE_3V3: J3.8, U3.14 (B4)
USR1_1V8: J3.15, J4.1
USR2_1V8: J3.16, J4.2
USR3_1V8: J3.17, J4.3
USR4_1V8: J3.18, J4.4
VCC: C4.1, J2.2, J6.1, RV1.1, U2.1 (DIR), U3.1 (DIR), U4.8 (VDD/VREF)
VCC_3V3: C1.1, C2.1, C3.1, J3.19, J6.16, U1.20 (VCC), U2.20 (VCC), U3.20 (VCC)
~CSR_3V3: J3.10, U3.15 (B3)
~CSR: J2.18, U1.19 (~0E), U3.5 (A3)
~CSW_3V3: J3.9, U3.16 (B2)
~CSW: J2.16, U2.19 (~0E), U3.4 (A2)
~INT_3V3: J3.11, U3.3 (A1)
~INT: J2.20, U3.17 (B1)
~RESET_3V3: J3.14, U3.18 (B0)
~RESET: J2.12, U3.2 (A0)

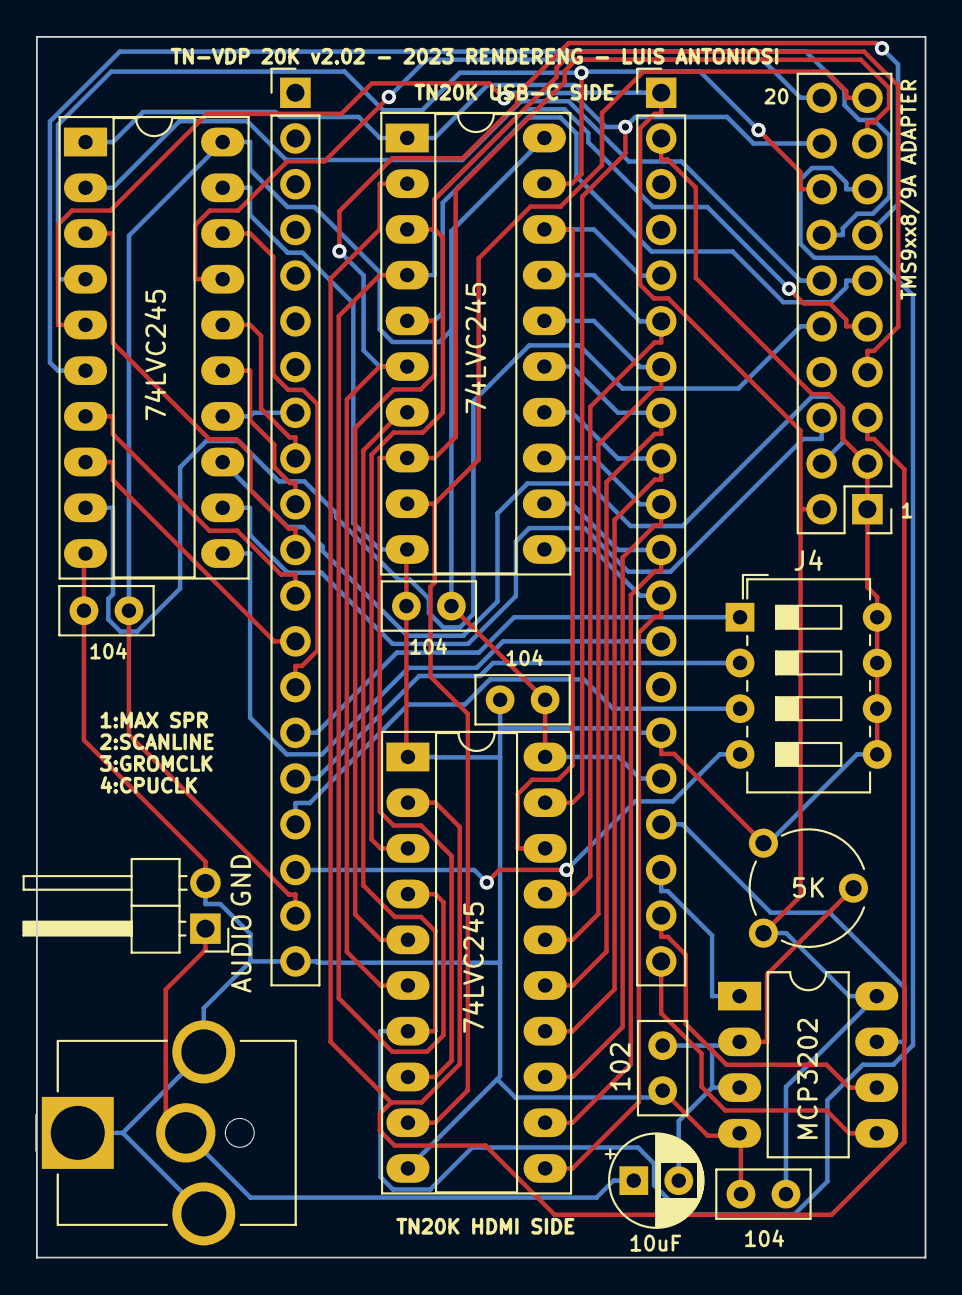
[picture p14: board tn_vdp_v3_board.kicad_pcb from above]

Board: 2 copper layers, 49.4 x 67.8 mm, 17 parts (0 on the bottom side), 45 nets.

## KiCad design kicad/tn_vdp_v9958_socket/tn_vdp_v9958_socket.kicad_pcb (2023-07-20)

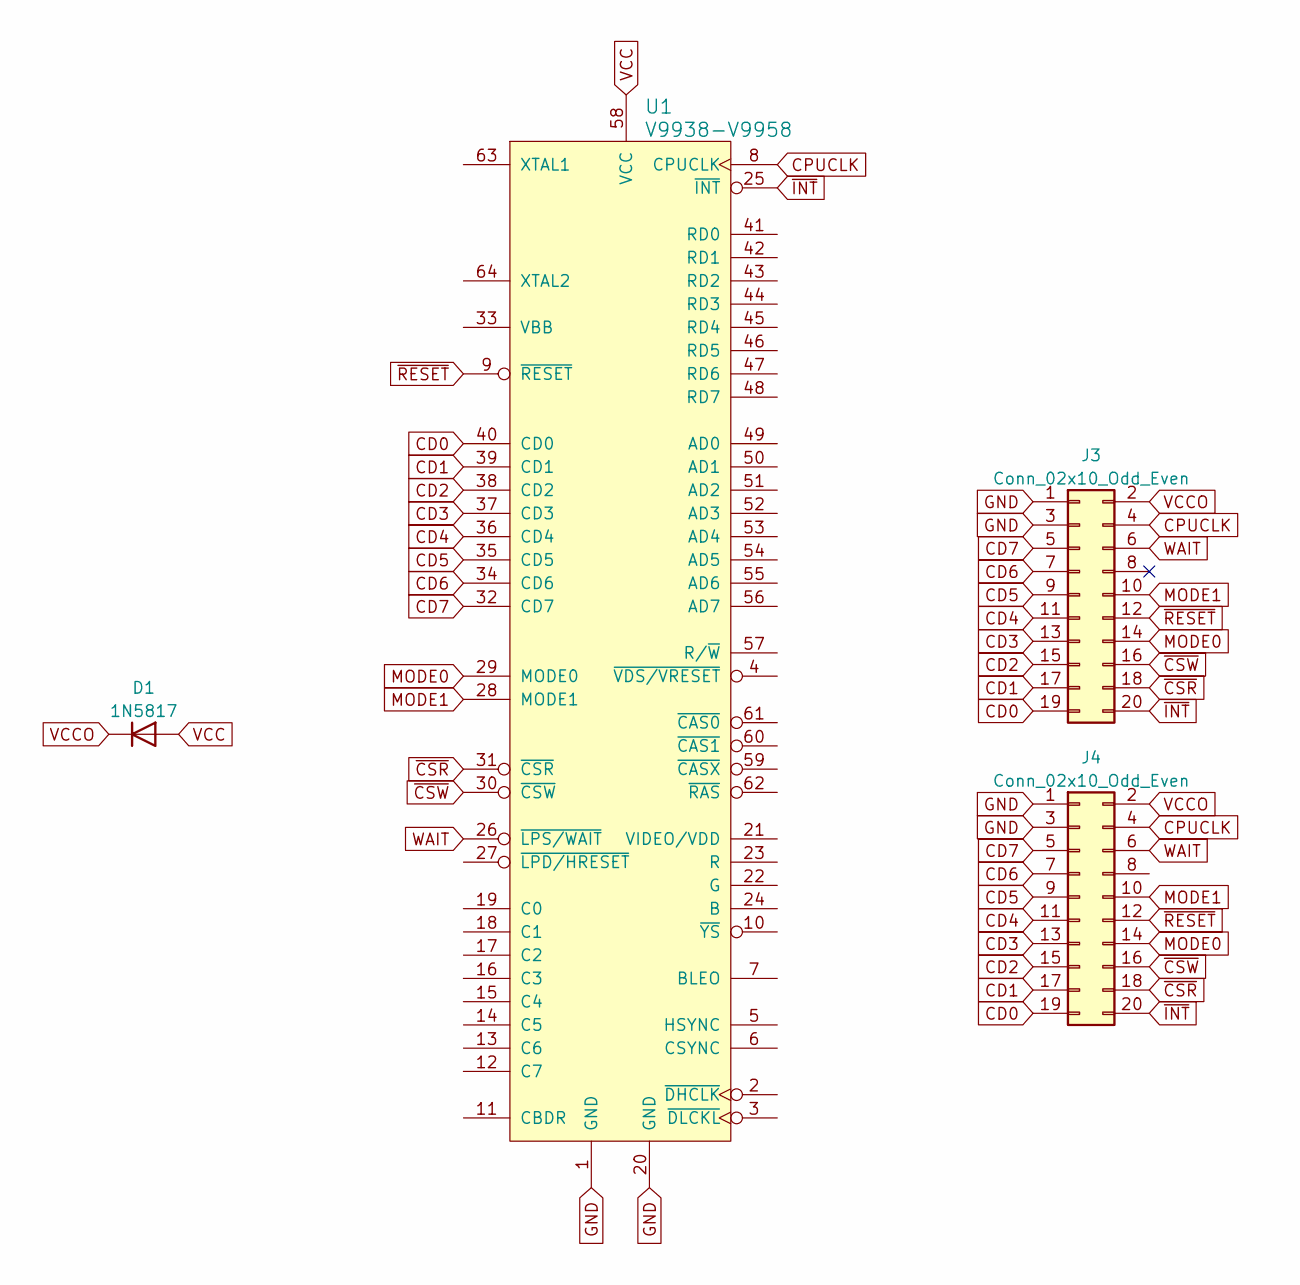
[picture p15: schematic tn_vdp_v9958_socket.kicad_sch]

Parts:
D1: 1N5817; D_DO-41_SOD81_P10.16mm_Horizontal
J3, J4: Conn_02x10_Odd_Even; PinHeader_2x10_P2.54mm_Vertical
U1: V9938-V9958; IC_SDIP64_600

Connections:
CD0: J3.19, J4.19, U1.40 (CD0)
CD1: J3.17, J4.17, U1.39 (CD1)
CD2: J3.15, J4.15, U1.38 (CD2)
CD3: J3.13, J4.13, U1.37 (CD3)
CD4: J3.11, J4.11, U1.36 (CD4)
CD5: J3.9, J4.9, U1.35 (CD5)
CD6: J3.7, J4.7, U1.34 (CD6)
CD7: J3.5, J4.5, U1.32 (CD7)
CPUCLK: J3.4, J4.4, U1.8 (CPUCLK)
GND: J3.1, J3.3, J4.1, J4.3, U1.1 (GND), U1.20 (GND)
MODE0: J3.14, J4.14, U1.29 (MODE0)
MODE1: J3.10, J4.10, U1.28 (MODE1)
VCC: D1.2 (A), U1.58 (VCC)
VCCO: D1.1 (K), J3.2, J4.2
WAIT: J3.6, J4.6, U1.26 (~LPS/WAIT)
~CSR: J3.18, J4.18, U1.31 (~CSR)
~CSW: J3.16, J4.16, U1.30 (~CSW)
~INT: J3.20, J4.20, U1.25 (~INT)
~RESET: J3.12, J4.12, U1.9 (~RESET)

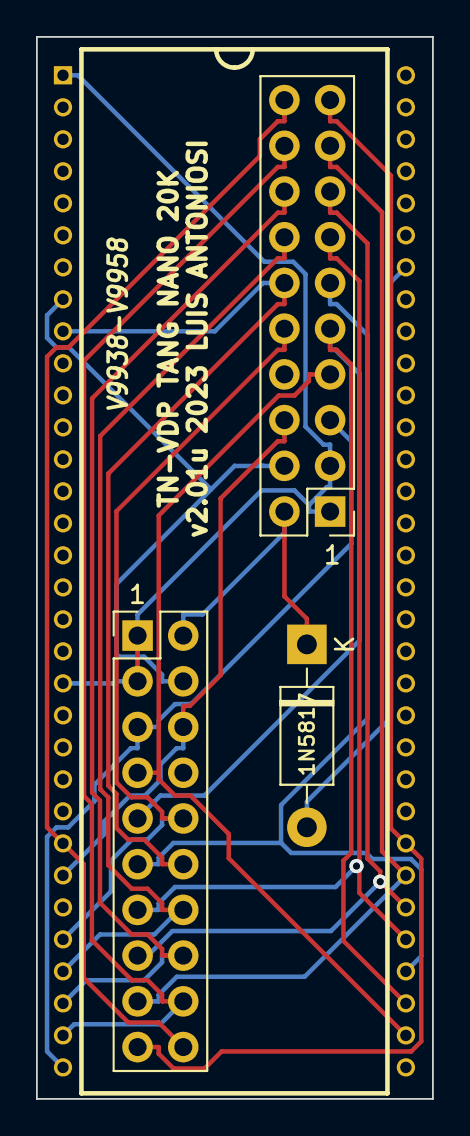
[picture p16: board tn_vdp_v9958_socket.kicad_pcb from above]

Board: 2 copper layers, 22.0 x 59.0 mm, 4 parts (0 on the bottom side), 19 nets.

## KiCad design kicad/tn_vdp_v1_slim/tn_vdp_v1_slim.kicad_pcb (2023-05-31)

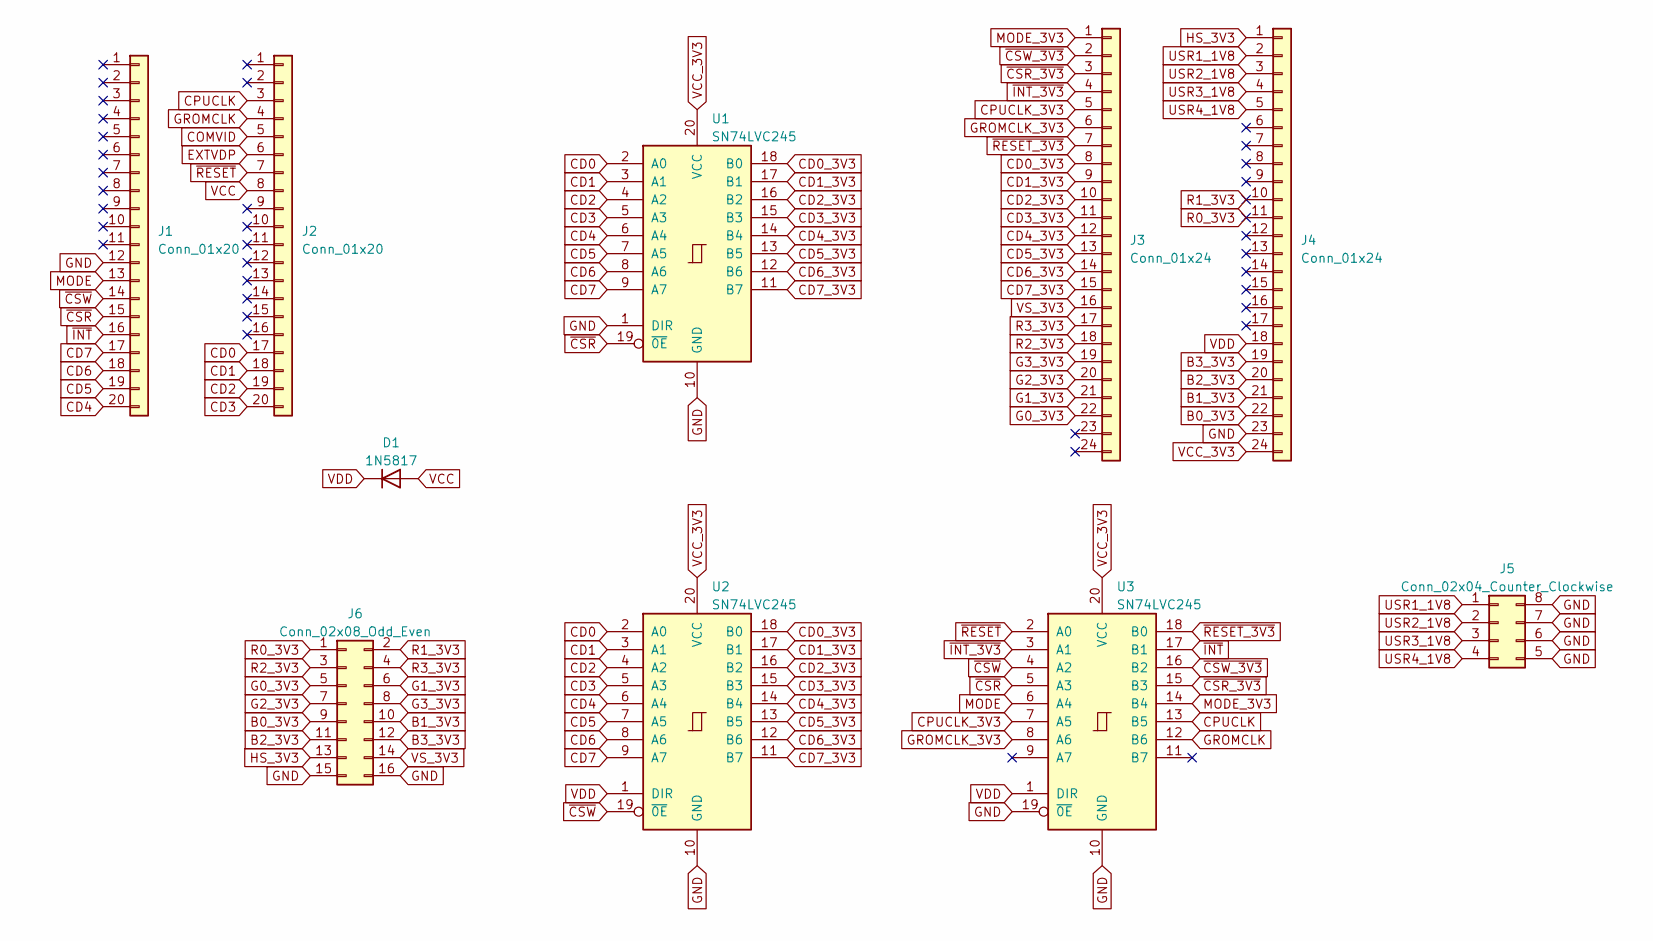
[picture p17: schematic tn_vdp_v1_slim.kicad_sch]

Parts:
D1: 1N5817; D_DO-41_SOD81_P10.16mm_Horizontal
J1, J2: Conn_01x20; PinHeader_1x20_P2.54mm_Vertical
J3, J4: Conn_01x24; PinSocket_1x24_P2.54mm_Vertical
J5: Conn_02x04_Counter_Clockwise; SW_DIP_SPSTx04_Slide_6.7x11.72mm_W7.62mm_P2.54mm_LowProfile
J6: Conn_02x08_Odd_Even; PinHeader_2x08_P2.54mm_Vertical
U1, U2, U3: SN74LVC245; DIP-20_W7.62mm_Socket_LongPads

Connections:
B0_3V3: J4.22, J6.9
B1_3V3: J4.21, J6.10
B2_3V3: J4.20, J6.11
B3_3V3: J4.19, J6.12
CD0: J2.17, U1.2 (A0), U2.2 (A0)
CD0_3V3: J3.8, U1.18 (B0), U2.18 (B0)
CD1: J2.18, U1.3 (A1), U2.3 (A1)
CD1_3V3: J3.9, U1.17 (B1), U2.17 (B1)
CD2: J2.19, U1.4 (A2), U2.4 (A2)
CD2_3V3: J3.10, U1.16 (B2), U2.16 (B2)
CD3: J2.20, U1.5 (A3), U2.5 (A3)
CD3_3V3: J3.11, U1.15 (B3), U2.15 (B3)
CD4: J1.20, U1.6 (A4), U2.6 (A4)
CD4_3V3: J3.12, U1.14 (B4), U2.14 (B4)
CD5: J1.19, U1.7 (A5), U2.7 (A5)
CD5_3V3: J3.13, U1.13 (B5), U2.13 (B5)
CD6: J1.18, U1.8 (A6), U2.8 (A6)
CD6_3V3: J3.14, U1.12 (B6), U2.12 (B6)
CD7: J1.17, U1.9 (A7), U2.9 (A7)
CD7_3V3: J3.15, U1.11 (B7), U2.11 (B7)
COMVID: J2.5
CPUCLK: J2.3, U3.13 (B5)
CPUCLK_3V3: J3.5, U3.7 (A5)
EXTVDP: J2.6
G0_3V3: J3.22, J6.5
G1_3V3: J3.21, J6.6
G2_3V3: J3.20, J6.7
G3_3V3: J3.19, J6.8
GND: J1.12, J4.23, J5.5, J5.6, J5.7, J5.8, J6.15, J6.16, U1.1 (DIR), U1.10 (GND), U2.10 (GND), U3.10 (GND), U3.19 (~0E)
GROMCLK: J2.4, U3.12 (B6)
GROMCLK_3V3: J3.6, U3.8 (A6)
HS_3V3: J4.1, J6.13
MODE: J1.13, U3.6 (A4)
MODE_3V3: J3.1, U3.14 (B4)
R0_3V3: J4.11, J6.1
R1_3V3: J4.10, J6.2
R2_3V3: J3.18, J6.3
R3_3V3: J3.17, J6.4
USR1_1V8: J4.2, J5.1
USR2_1V8: J4.3, J5.2
USR3_1V8: J4.4, J5.3
USR4_1V8: J4.5, J5.4
VCC: D1.2 (A), J2.8
VCC_3V3: J4.24, U1.20 (VCC), U2.20 (VCC), U3.20 (VCC)
VDD: D1.1 (K), J4.18, U2.1 (DIR), U3.1 (DIR)
VS_3V3: J3.16, J6.14
~CSR_3V3: J3.3, U3.15 (B3)
~CSR: J1.15, U1.19 (~0E), U3.5 (A3)
~CSW_3V3: J3.2, U3.16 (B2)
~CSW: J1.14, U2.19 (~0E), U3.4 (A2)
~INT_3V3: J3.4, U3.3 (A1)
~INT: J1.16, U3.17 (B1)
~RESET_3V3: J3.7, U3.18 (B0)
~RESET: J2.7, U3.2 (A0)

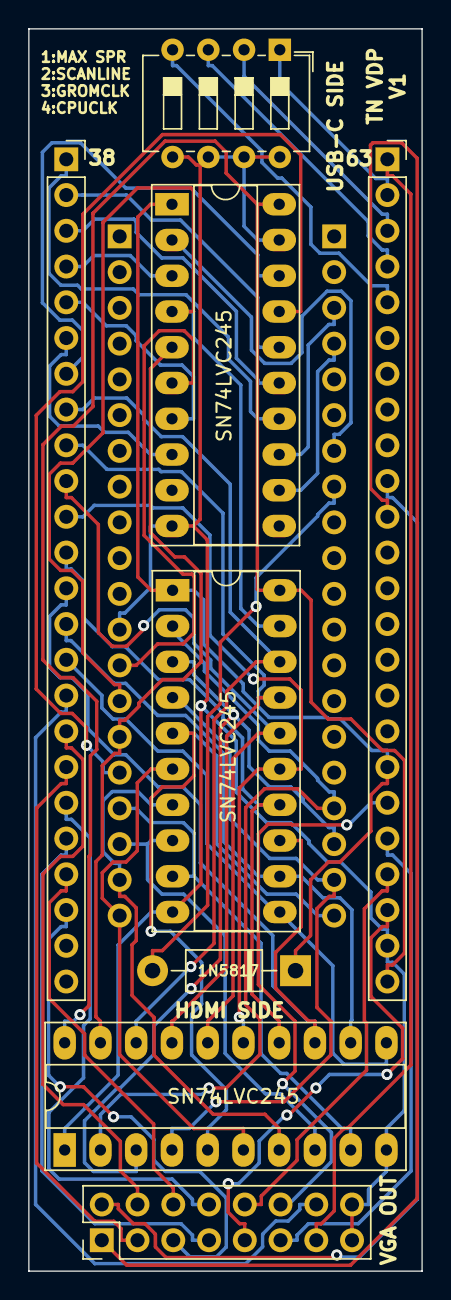
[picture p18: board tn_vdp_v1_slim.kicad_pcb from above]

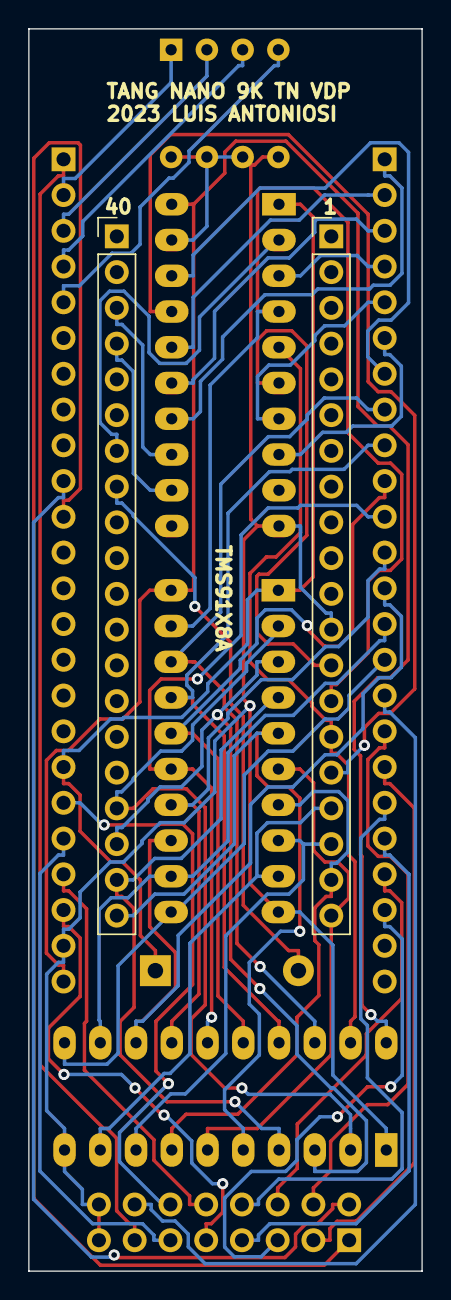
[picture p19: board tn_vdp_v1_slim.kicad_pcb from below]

Board: 2 copper layers, 27.9 x 88.3 mm, 10 parts (2 on the bottom side), 52 nets.

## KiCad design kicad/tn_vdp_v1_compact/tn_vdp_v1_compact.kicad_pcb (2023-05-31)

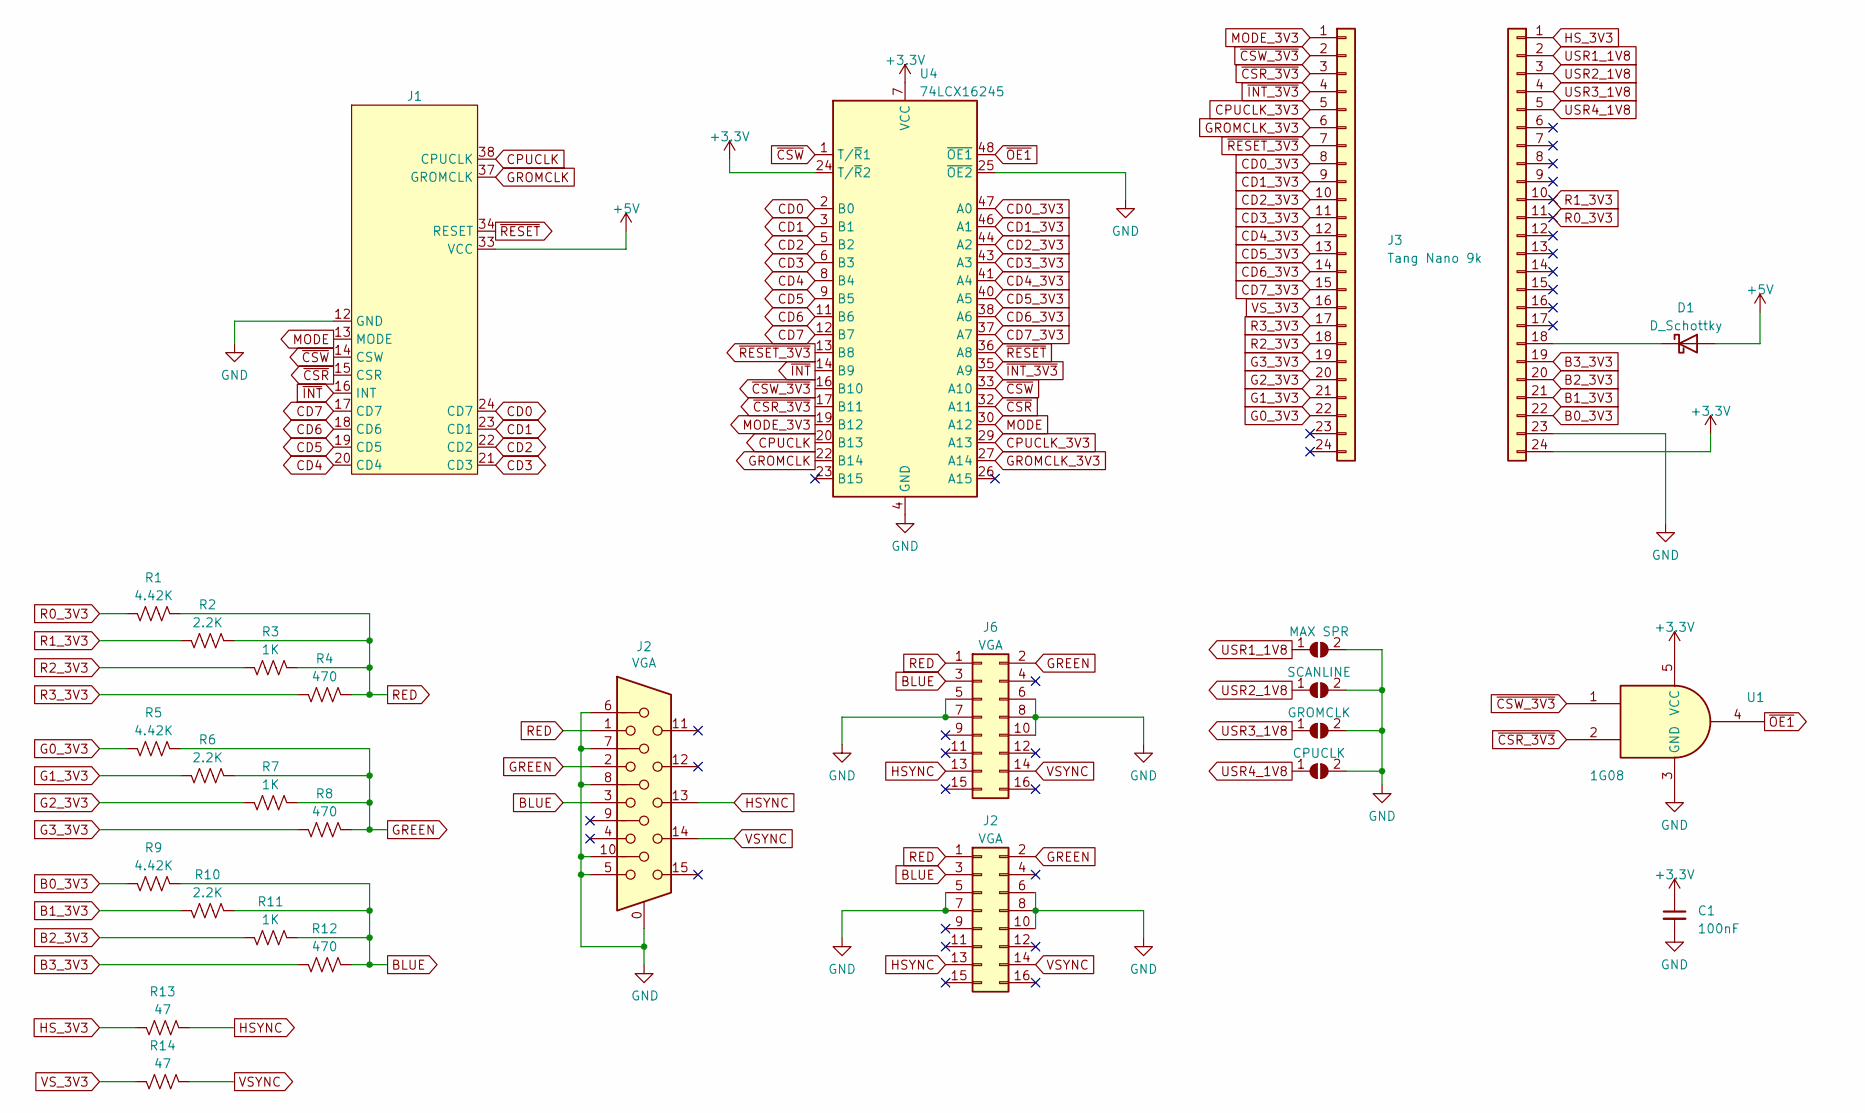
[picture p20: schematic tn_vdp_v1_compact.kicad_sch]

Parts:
C1: 100nF; C_0603_1608Metric_Pad1.08x0.95mm_HandSolder; LCSC C2857981
D1: D_Schottky; D_SOD-123; LCSC C2900723
J1: TMS99xxA_Replacement
J2: VGA; DSUB-15-HD_Female_Horizontal_P2.29x1.98mm_EdgePinOffset3.03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
J3: Tang Nano 9k; PinSocket_1x24_P2.54mm_Vertical
J4: TN9k/2; PinSocket_1x24_P2.54mm_Vertical
J6: VGA; PinHeader_2x08_P2.54mm_Vertical
JP1: MAX SPR; SolderJumper-2_P1.3mm_Open_RoundedPad1.0x1.5mm
JP2: SCANLINE; SolderJumper-2_P1.3mm_Open_RoundedPad1.0x1.5mm
JP3: GROMCLK; SolderJumper-2_P1.3mm_Open_RoundedPad1.0x1.5mm
JP4: CPUCLK; SolderJumper-2_P1.3mm_Open_RoundedPad1.0x1.5mm
R1, R5, R9: 4.42K; R_0603_1608Metric_Pad0.98x0.95mm_HandSolder; LCSC C5140130
R2, R6, R10: 2.2K; R_0603_1608Metric_Pad0.98x0.95mm_HandSolder; LCSC C3016472
R3, R7, R11: 1K; R_0603_1608Metric_Pad0.98x0.95mm_HandSolder; LCSC C3016283
R4, R8, R12: 470; R_0603_1608Metric_Pad0.98x0.95mm_HandSolder; LCSC C103660
R13, R14: 47; R_0603_1608Metric_Pad0.98x0.95mm_HandSolder; LCSC C3016437
U1: 1G08; SOT-23-5_HandSoldering; LCSC C7666
U4: 74LCX16245; TSSOP-48_6.1x12.5mm_P0.5mm; LCSC C894789

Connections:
+3.3V: C1.1, J4.24, U1.5 (VCC), U4.7 (VCC), U4.18 (VCC), U4.24 (T/~R2), U4.31 (VCC), U4.42 (VCC)
+5V: D1.2 (A), J1.33 (VCC)
B0_3V3: J4.22, R9.2
B1_3V3: J4.21, R10.2
B2_3V3: J4.20, R11.2
B3_3V3: J4.19, R12.2
BLUE: J2.3, J6.3, R9.1, R10.1, R11.1, R12.1; also elsewhere on the board
CD0: J1.24 (CD7), U4.2 (B0)
CD0_3V3: J3.8, U4.47 (A0)
CD1: J1.23 (CD1), U4.3 (B1)
CD1_3V3: J3.9, U4.46 (A1)
CD2: J1.22 (CD2), U4.5 (B2)
CD2_3V3: J3.10, U4.44 (A2)
CD3: J1.21 (CD3), U4.6 (B3)
CD3_3V3: J3.11, U4.43 (A3)
CD4: J1.20 (CD4), U4.8 (B4)
CD4_3V3: J3.12, U4.41 (A4)
CD5: J1.19 (CD5), U4.9 (B5)
CD5_3V3: J3.13, U4.40 (A5)
CD6: J1.18 (CD6), U4.11 (B6)
CD6_3V3: J3.14, U4.38 (A6)
CD7: J1.17 (CD7), U4.12 (B7)
CD7_3V3: J3.15, U4.37 (A7)
CPUCLK: J1.38 (CPUCLK), U4.20 (B13)
CPUCLK_3V3: J3.5, U4.29 (A13)
G0_3V3: J3.22, R5.2
G1_3V3: J3.21, R6.2
G2_3V3: J3.20, R7.2
G3_3V3: J3.19, R8.2
GND: C1.2, J1.12 (GND), J2.0, J2.5, J2.6, J2.7, J2.8, J2.10, J4.23, J6.5, J6.6, J6.7, J6.8, J6.10, JP1.2 (B), JP2.2 (B), JP3.2 (B), JP4.2 (B), U1.3 (GND), U4.4 (GND), U4.10 (GND), U4.15 (GND), U4.21 (GND), U4.25 (~OE2), U4.28 (GND), U4.34 (GND), U4.39 (GND), U4.45 (GND); also elsewhere on the board
GREEN: J2.2, J6.2, R5.1, R6.1, R7.1, R8.1; also elsewhere on the board
GROMCLK: J1.37 (GROMCLK), U4.22 (B14)
GROMCLK_3V3: J3.6, U4.27 (A14)
HSYNC: J2.13, J6.13, R13.1; also elsewhere on the board
HS_3V3: J4.1, R13.2
MODE: J1.13 (MODE), U4.30 (A12)
MODE_3V3: J3.1, U4.19 (B12)
unnamed: D1.1 (K), J4.18
R0_3V3: J4.11, R1.2
R1_3V3: J4.10, R2.2
R2_3V3: J3.18, R3.2
R3_3V3: J3.17, R4.2
RED: J2.1, J6.1, R1.1, R2.1, R3.1, R4.1; also elsewhere on the board
USR1_1V8: J4.2, JP1.1 (A)
USR2_1V8: J4.3, JP2.1 (A)
USR3_1V8: J4.4, JP3.1 (A)
USR4_1V8: J4.5, JP4.1 (A)
VSYNC: J2.14, J6.14, R14.1; also elsewhere on the board
VS_3V3: J3.16, R14.2
~CSR_3V3: J3.3, U1.2, U4.17 (B11)
~CSR: J1.15 (CSR), U4.32 (A11)
~CSW_3V3: J3.2, U1.1, U4.16 (B10)
~CSW: J1.14 (CSW), U4.1 (T/~R1), U4.33 (A10)
~INT_3V3: J3.4, U4.35 (A9)
~INT: J1.16 (INT), U4.14 (B9)
~OE1: U1.4, U4.48 (~OE1)
~RESET_3V3: J3.7, U4.13 (B8)
~RESET: J1.34 (RESET), U4.36 (A8)

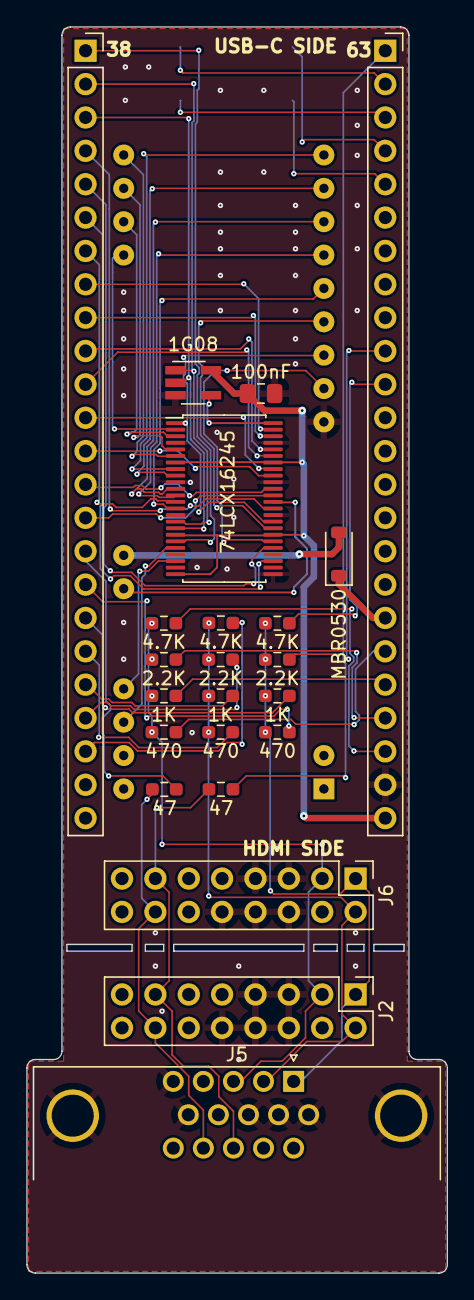
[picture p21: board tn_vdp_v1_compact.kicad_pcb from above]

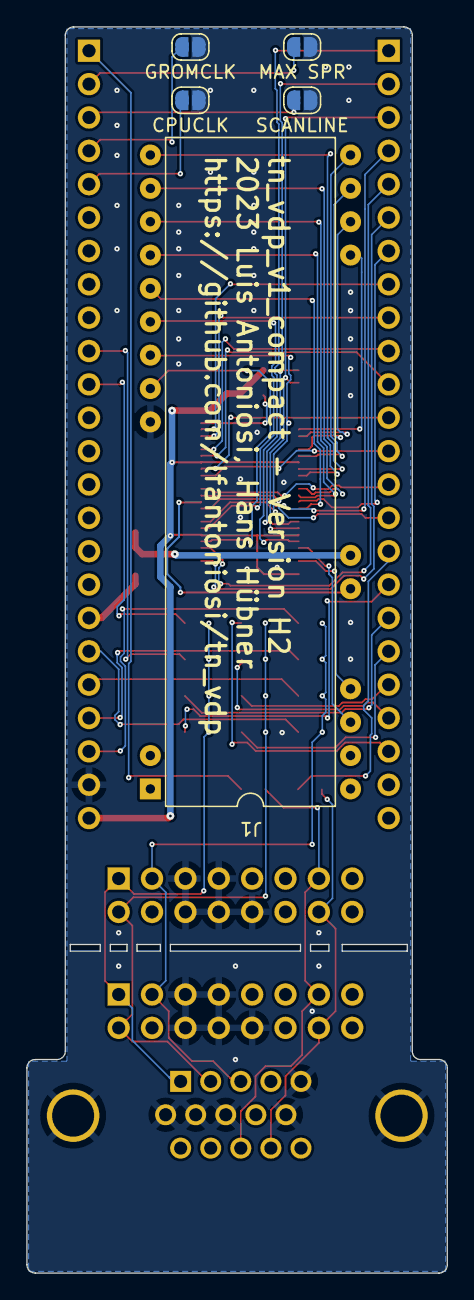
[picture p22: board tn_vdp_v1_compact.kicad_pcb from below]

Board: 2 copper layers, 32.0 x 94.9 mm, 28 parts (4 on the bottom side), 58 nets.

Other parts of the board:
J5: VGA; DSUB-15-HD_Female_Horizontal_P2.29x1.98mm_EdgePinOffset3.03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

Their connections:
BLUE: J5.3; also elsewhere on the board
GND: J5.0, J5.5, J5.6, J5.7, J5.8, J5.10; also elsewhere on the board
GREEN: J5.2; also elsewhere on the board
HSYNC: J5.13; also elsewhere on the board
RED: J5.1; also elsewhere on the board
VSYNC: J5.14; also elsewhere on the board

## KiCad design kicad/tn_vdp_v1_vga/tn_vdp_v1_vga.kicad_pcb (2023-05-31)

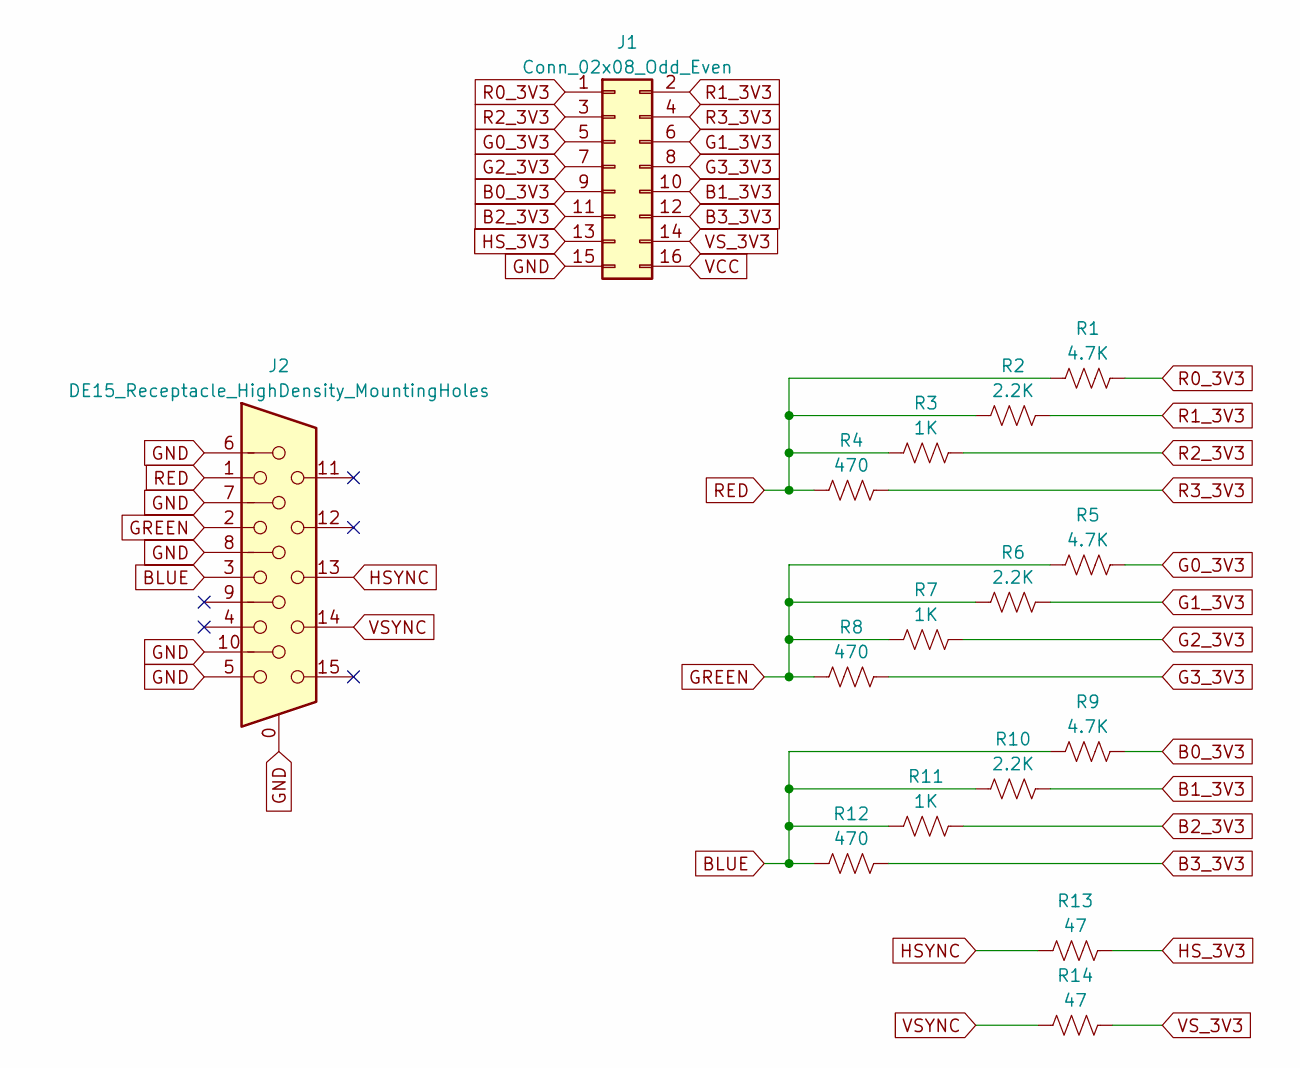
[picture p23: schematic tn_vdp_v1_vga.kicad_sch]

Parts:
J1: Conn_02x08_Odd_Even; PinHeader_2x08_P2.54mm_Vertical
J2: DE15_Receptacle_HighDensity_MountingHoles; DSUB-15-HD_Female_Horizontal_P2.29x1.98mm_EdgePinOffset3.03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
R1, R5, R9: 4.7K; R_Axial_DIN0207_L6.3mm_D2.5mm_P10.16mm_Horizontal
R2, R6, R10: 2.2K; R_Axial_DIN0207_L6.3mm_D2.5mm_P10.16mm_Horizontal
R3, R7, R11: 1K; R_Axial_DIN0207_L6.3mm_D2.5mm_P10.16mm_Horizontal
R4, R8, R12: 470; R_Axial_DIN0207_L6.3mm_D2.5mm_P10.16mm_Horizontal
R13, R14: 47; R_Axial_DIN0207_L6.3mm_D2.5mm_P10.16mm_Horizontal

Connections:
B0_3V3: J1.9, R9.2
B1_3V3: J1.10, R10.2
B2_3V3: J1.11, R11.2
B3_3V3: J1.12, R12.2
BLUE: J2.3, R9.1, R10.1, R11.1, R12.1
G0_3V3: J1.5, R5.2
G1_3V3: J1.6, R6.2
G2_3V3: J1.7, R7.2
G3_3V3: J1.8, R8.2
GND: J1.15, J2.0, J2.5, J2.6, J2.7, J2.8, J2.10
GREEN: J2.2, R5.1, R6.1, R7.1, R8.1
HSYNC: J2.13, R13.1
HS_3V3: J1.13, R13.2
R0_3V3: J1.1, R1.2
R1_3V3: J1.2, R2.2
R2_3V3: J1.3, R3.2
R3_3V3: J1.4, R4.2
RED: J2.1, R1.1, R2.1, R3.1, R4.1
VCC: J1.16
VSYNC: J2.14, R14.1
VS_3V3: J1.14, R14.2

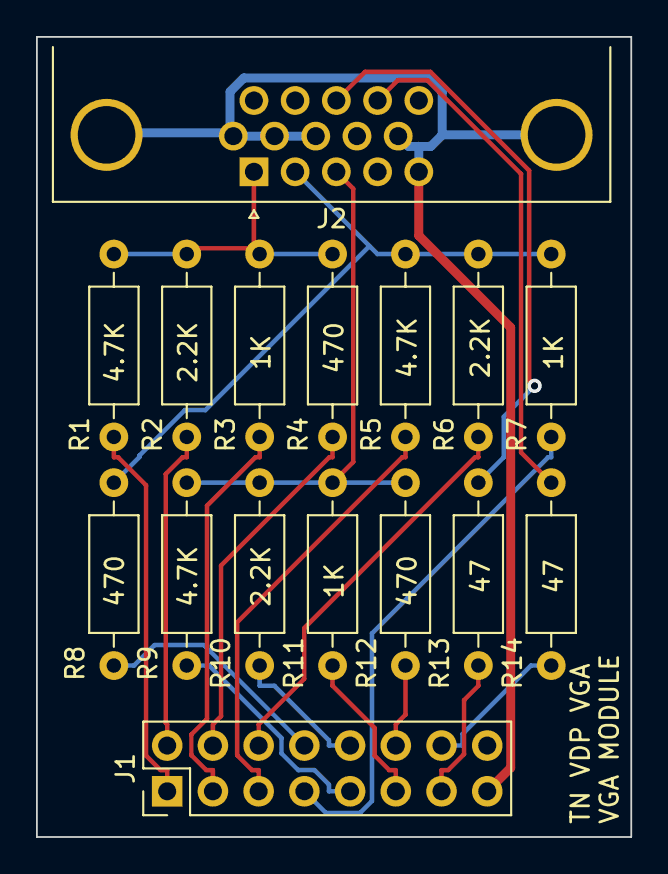
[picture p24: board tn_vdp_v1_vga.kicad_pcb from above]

Board: 2 copper layers, 33.0 x 44.5 mm, 16 parts (0 on the bottom side), 20 nets.

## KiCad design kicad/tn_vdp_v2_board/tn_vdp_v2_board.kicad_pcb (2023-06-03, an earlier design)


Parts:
C1, C2, C3, C4: 104; C_Disc_D5.0mm_W2.5mm_P2.50mm
H1, H2, H3, H4: MountingHole; MountingHole_2.2mm_M2_ISO7380_Pad
J1, J2: Conn_02x10_Odd_Even; PinHeader_2x10_P2.54mm_Vertical
J3, J4: Conn_01x24; PinSocket_1x24_P2.54mm_Vertical
J7: Conn_02x04_Counter_Clockwise; PinHeader_2x04_P2.54mm_Vertical
U1, U2, U3: SN74LVC245; DIP-20_W7.62mm_Socket_LongPads
U4: MCP3202; DIP-8_W7.62mm_LongPads

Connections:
ADC_CLK: J4.19, U4.7 (CLK)
ADC_CS: J4.20, U4.1 (~CS/SHDN)
ADC_MISO: J4.21, U4.6 (DOUT)
ADC_MOSI: J4.22, U4.5 (DIN)
AUDIO: J1.8, J2.8, U4.2 (CH0), U4.3 (CH1)
CD0: J1.5, J2.5, U1.2 (A0), U2.2 (A0)
CD0_3V3: J3.8, U1.18 (B0), U2.18 (B0)
CD1: J1.7, J2.7, U1.3 (A1), U2.3 (A1)
CD1_3V3: J3.9, U1.17 (B1), U2.17 (B1)
CD2: J1.9, J2.9, U1.4 (A2), U2.4 (A2)
CD2_3V3: J3.10, U1.16 (B2), U2.16 (B2)
CD3: J1.11, J2.11, U1.5 (A3), U2.5 (A3)
CD3_3V3: J3.11, U1.15 (B3), U2.15 (B3)
CD4: J1.13, J2.13, U1.6 (A4), U2.6 (A4)
CD4_3V3: J3.12, U1.14 (B4), U2.14 (B4)
CD5: J1.15, J2.15, U1.7 (A5), U2.7 (A5)
CD5_3V3: J3.13, U1.13 (B5), U2.13 (B5)
CD6: J1.17, J2.17, U1.8 (A6), U2.8 (A6)
CD6_3V3: J3.14, U1.12 (B6), U2.12 (B6)
CD7: J1.19, J2.19, U1.9 (A7), U2.9 (A7)
CD7_3V3: J3.15, U1.11 (B7), U2.11 (B7)
CPUCLK: J1.4, J2.4, U3.13 (B5)
CPUCLK_3V3: J3.5, U3.7 (A5)
GND: C1.2, C2.2, C3.2, C4.2, J1.1, J1.3, J2.1, J2.3, J4.23, J7.2, J7.4, J7.6, J7.8, U1.1 (DIR), U1.10 (GND), U2.10 (GND), U3.10 (GND), U3.19 (~0E), U4.4 (VSS)
GROMCLK: J1.6, J2.6, U3.12 (B6)
GROMCLK_3V3: J3.6, U3.8 (A6)
MODE: J1.14, J2.14, U3.6 (A4)
MODE1: J1.10, J2.10, U3.9 (A7)
MODE1_3V3: J3.16, U3.11 (B7)
MODE_3V3: J3.1, U3.14 (B4)
USR1_1V8: J4.2, J7.1
USR2_1V8: J4.3, J7.3
USR3_1V8: J4.4, J7.5
USR4_1V8: J4.5, J7.7
VCC: J1.2, J2.2, J4.18, U2.1 (DIR), U3.1 (DIR)
VCC_3V3: C1.1, C2.1, C3.1, C4.1, J4.24, U1.20 (VCC), U2.20 (VCC), U3.20 (VCC), U4.8 (VDD/VREF)
~CSR_3V3: J3.3, U3.15 (B3)
~CSR: J1.18, J2.18, U1.19 (~0E), U3.5 (A3)
~CSW_3V3: J3.2, U3.16 (B2)
~CSW: J1.16, J2.16, U2.19 (~0E), U3.4 (A2)
~INT_3V3: J3.4, U3.3 (A1)
~INT: J1.20, J2.20, U3.17 (B1)
~RESET_3V3: J3.7, U3.18 (B0)
~RESET: J1.12, J2.12, U3.2 (A0)


Board: 2 copper layers, 51.9 x 67.8 mm, 17 parts (0 on the bottom side), 44 nets.

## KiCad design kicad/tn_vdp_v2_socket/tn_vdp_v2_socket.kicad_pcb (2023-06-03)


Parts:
D1: 1N5817; D_DO-41_SOD81_P10.16mm_Horizontal
J1, J2: Conn_01x20; PinHeader_1x20_P2.54mm_Vertical
J3, J4: Conn_02x10_Odd_Even; PinHeader_2x10_P2.54mm_Vertical
J5: Conn_01x02; PinHeader_1x02_P2.54mm_Vertical

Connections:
AUDIO: J3.8, J4.8, J5.1
CD0: J2.17, J3.5, J4.5
CD1: J2.18, J3.7, J4.7
CD2: J2.19, J3.9, J4.9
CD3: J2.20, J3.11, J4.11
CD4: J1.20, J3.13, J4.13
CD5: J1.19, J3.15, J4.15
CD6: J1.18, J3.17, J4.17
CD7: J1.17, J3.19, J4.19
CPUCLK: J2.3, J3.4, J4.4
GND: J1.12, J3.1, J3.3, J4.1, J4.3
GROMCLK: J2.4, J3.6, J4.6
MODE0: J1.13, J3.14, J4.14
MODE1: J3.10, J4.10, J5.2
VCC: D1.2 (A), J2.8
VCCO: D1.1 (K), J3.2, J4.2
~CSR: J1.15, J3.18, J4.18
~CSW: J1.14, J3.16, J4.16
~INT: J1.16, J3.20, J4.20
~RESET: J2.7, J3.12, J4.12



Board: 2 copper layers, 20.3 x 53.3 mm, 6 parts (2 on the bottom side), 20 nets.

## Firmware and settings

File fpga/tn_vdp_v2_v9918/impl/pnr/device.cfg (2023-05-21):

set JTAG regular_io = false
set SSPI regular_io = true
set MSPI regular_io = true
set READY regular_io = false
set DONE regular_io = false
set RECONFIG_N regular_io = false
set I2C regular_io = false
set CRC_check = true
set compress = true
set encryption = false
set security_bit_enable = true
set bsram_init_fuse_print = true
set background_programming = off
set secure_mode = false
set download_speed = 250/10
set program_done_bypass = false
set wake_up = 0
set spi_flash_address = 0x00000000
set format = binary
set power_on_reset_monitor = true
set unused_pin = default

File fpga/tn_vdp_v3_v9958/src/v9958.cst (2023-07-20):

//Copyright (C)2014-2023 Gowin Semiconductor Corporation.
//All rights reserved. 
//File Title: Physical Constraints file
//GOWIN Version: 1.9.8.11 Education
//Part Number: GW2AR-LV18QN88C8/I7
//Device: GW2AR-18
//Device Version: C
//Created Time: Wed 07 19 21:03:46 2023

IO_LOC "clk" 4;
IO_PORT "clk" PULL_MODE=UP;

IO_LOC "clk_50" 10;
IO_PORT "clk_50" PULL_MODE=UP;

IO_LOC "clk_125" 11;
IO_PORT "clk_125" PULL_MODE=UP;

IO_LOC "s1" 88;
IO_PORT "s1" PULL_MODE=DOWN;

IO_LOC "adc_mosi" 52;
IO_PORT "adc_mosi" IO_TYPE=LVCMOS33 PULL_MODE=DOWN DRIVE=16;
IO_LOC "adc_cs" 71;
IO_PORT "adc_cs" IO_TYPE=LVCMOS33 PULL_MODE=DOWN DRIVE=16;
IO_LOC "adc_clk" 72;
IO_PORT "adc_clk" IO_TYPE=LVCMOS33 PULL_MODE=DOWN DRIVE=16;
IO_LOC "adc_miso" 53;
IO_PORT "adc_miso" IO_TYPE=LVCMOS33 PULL_MODE=DOWN;

IO_LOC "gromclk" 30;
IO_PORT "gromclk" IO_TYPE=LVCMOS33 PULL_MODE=UP DRIVE=16;
IO_LOC "cpuclk" 29;
IO_PORT "cpuclk" IO_TYPE=LVCMOS33 PULL_MODE=UP DRIVE=16;

IO_LOC "csr_n" 25;
IO_PORT "csr_n" IO_TYPE=LVCMOS33 PULL_MODE=UP;
IO_LOC "csw_n" 28;
IO_PORT "csw_n" IO_TYPE=LVCMOS33 PULL_MODE=UP;
IO_LOC "mode[1]" 86;
IO_PORT "mode[1]" IO_TYPE=LVCMOS33 PULL_MODE=DOWN;
IO_LOC "mode[0]" 27;
IO_PORT "mode[0]" IO_TYPE=LVCMOS33 PULL_MODE=DOWN;
IO_LOC "reset_n" 31;
IO_PORT "reset_n" IO_TYPE=LVCMOS33 PULL_MODE=UP;
IO_LOC "int_n" 26;
IO_PORT "int_n" IO_TYPE=LVCMOS33 PULL_MODE=UP DRIVE=16;

IO_LOC "cd[7]" 42;
IO_PORT "cd[7]" IO_TYPE=LVCMOS33 PULL_MODE=NONE DRIVE=16;
IO_LOC "cd[6]" 41;
IO_PORT "cd[6]" IO_TYPE=LVCMOS33 PULL_MODE=NONE DRIVE=16;
IO_LOC "cd[5]" 56;
IO_PORT "cd[5]" IO_TYPE=LVCMOS33 PULL_MODE=NONE DRIVE=16;
IO_LOC "cd[4]" 54;
IO_PORT "cd[4]" IO_TYPE=LVCMOS33 PULL_MODE=NONE DRIVE=16;
IO_LOC "cd[3]" 51;
IO_PORT "cd[3]" IO_TYPE=LVCMOS33 PULL_MODE=NONE DRIVE=16;
IO_LOC "cd[2]" 48;
IO_PORT "cd[2]" IO_TYPE=LVCMOS33 PULL_MODE=NONE DRIVE=16;
IO_LOC "cd[1]" 55;
IO_PORT "cd[1]" IO_TYPE=LVCMOS33 PULL_MODE=NONE DRIVE=16;
IO_LOC "cd[0]" 49;
IO_PORT "cd[0]" IO_TYPE=LVCMOS33 PULL_MODE=NONE DRIVE=16;

IO_LOC "cpuclk_ena_n" 18;
IO_PORT "cpuclk_ena_n" IO_TYPE=LVCMOS33 PULL_MODE=UP;
IO_LOC "gromclk_ena_n" 19;
IO_PORT "gromclk_ena_n" IO_TYPE=LVCMOS33 PULL_MODE=UP;
IO_LOC "scanlin_n" 20;
IO_PORT "scanlin_n" IO_TYPE=LVCMOS33 PULL_MODE=UP;
IO_LOC "maxspr_n" 17;
IO_PORT "maxspr_n" IO_TYPE=LVCMOS33 PULL_MODE=UP;

IO_LOC "tmds_data_p[0]" 35,36;
IO_PORT "tmds_data_p[0]" IO_TYPE=LVCMOS33D PULL_MODE=NONE DRIVE=16;
IO_LOC "tmds_data_p[1]" 37,38;
IO_PORT "tmds_data_p[1]" IO_TYPE=LVCMOS33D PULL_MODE=NONE DRIVE=16;
IO_LOC "tmds_data_p[2]" 39,40;
IO_PORT "tmds_data_p[2]" IO_TYPE=LVCMOS33D PULL_MODE=NONE DRIVE=16;
IO_LOC "tmds_clk_p" 33,34;
IO_PORT "tmds_clk_p" IO_TYPE=LVCMOS33D PULL_MODE=NONE DRIVE=16;

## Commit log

2023-05-02 adding FAT version
    [tn9k_f18_fat-B_Cu.gbr, tn9k_f18_fat-B_Mask.gbr, tn9k_f18_fat-B_Paste.gbr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]
2023-05-02 update silk on fat board
    [tn9k_f18_fat-B_Cu.gbr, tn9k_f18_fat-B_Mask.gbr, tn9k_f18_fat-B_Paste.gbr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]
2023-05-04 fat board
2023-05-13 fixing power on gromclk
    NABU PC nows seems to boot normally from cold-boot
2023-05-16 nabu backplate model
    [nabu-backplate.FCStd, nabu-backplate.stl]
2023-05-19 faster power on
2023-05-20 rename files for matching case
2023-05-21 remove power on wait and disable user SPI lines
    hdmi sink seems to conflict with spi user at startup causing the f118 to slow. I have no idea but disabling them seems to solve the boot time with hdmi
2023-05-21 booting code faster
    adding compress to the code, loads faster
    remove drive constraints
    restoring spi lines
    [device.cfg]
2023-05-22 SMD version
    [tn9k_f18a-B_Cu.gbr, tn9k_f18a-B_Mask.gbr, tn9k_f18a-B_Paste.gbr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]
2023-05-22 save work
    [tn9k_f18a.kicad_pcb]
2023-05-22 silkscreen tweaks
    [tn9k_f18a.kicad_pcb]
2023-05-22 Version H1 sent to aisler
    [tn9k_f18a-B_Cu.gbr, tn9k_f18a-B_Mask.gbr, tn9k_f18a-B_Paste.gbr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]
2023-05-22 re-add original board
    [tn9k_f18a-B_Cu.gbr, tn9k_f18a-B_Mask.gbr, tn9k_f18a-B_Paste.gbr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]
2023-05-22 rename compact version files
    [tn9k_f18a_compact.kicad_pcb, tn9k_f18a_compact.kicad_sch]
2023-05-22 Add diode to prevent host being powered from TN9k
    HDMI has a +5V supply line that could halfway power up the TI-99/4A
    [tn9k_f18a_compact.kicad_pcb, tn9k_f18a_compact.kicad_sch]
2023-05-22 Schematics PDF
2023-05-22 Update gerbers
2023-05-22 update FAT board for the diode
    [tn9k_f18_fat-B_Cu.gbr, tn9k_f18_fat-B_Mask.gbr, tn9k_f18_fat-B_Paste.gbr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]
2023-05-22 update original board adding diode
    [tn9k_f18a-B_Cu.gbr, tn9k_f18a-B_Mask.gbr, tn9k_f18a-B_Paste.gbr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]
2023-05-24 Add BOM
    [tn9k_f18a_compact.csv, tn9k_f18a_compact.kicad_sch]
2023-05-31 rebrand to TN VDP
    [device.cfg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]
2023-05-31 rebrand of the compact version + license update
    [tn_vdp_v1_compact.csv, tn_vdp_v1_compact.kicad_pcb, tn_vdp_v1_compact.kicad_sch]
2023-06-03 HDMI AUDIO
    Board V2
    Code V2 for V9918
    New core V9958 (V2)
    [device.cfg, mainboard.kicad_pcb, mainboard.kicad_sch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]
2023-06-06 add maxspr swtich to v9958
    [device.cfg]
2023-06-07 fix sprite multiplexing
    [device.cfg]
2023-06-09 fix timings on 9958
    [device.cfg]
2023-06-11 moving stuff around
    [tn_vdp_v1_compact.csv, tn_vdp_v1_compact.kicad_pcb, tn_vdp_v1_compact.kicad_sch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]
2023-06-11 moving stuff
    [tn_vdp_v1_compact.csv, tn_vdp_v1_compact.kicad_pcb, tn_vdp_v1_compact.kicad_sch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]
2023-07-01 V3 Tang 20k Board and FPGA
    [device.cfg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]
2023-07-11 fix v2 9958 sync
    [v9958.cst]
2023-07-15 adding low pass filter to audio + other improvements
2023-07-16 improving stability and precision of clock dividers
    [tn_vdp_v3_board.kicad_pcb, tn_vdp_v3_board.kicad_sch]
2023-07-17 new clocks 3.58Mhz !!!
    [tn_vdp_v3_board.kicad_pcb, tn_vdp_v3_board.kicad_sch]
2023-07-18 revert some clk changes + add support to v9958 socket
2023-07-20 stability fixres plus interrupt
    [v9958.cst]
2023-07-20 V9958 Socket + New V3 Board (audio fix + cinch connector)
    [tn_vdp_v3_board-B_Cu.gbr, tn_vdp_v3_board-B_Mask.gbr, tn_vdp_v3_board-B_Paste.gbr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]
2023-07-21 improved clock 3.580Mhz + interrupt timers corrected
2023-07-23 revert CD (9958 prototype got it reversed)
2023-07-30 interrupt boundary
2023-08-12 left mask bug
    msx2+ logo now works
    [device.cfg]
2023-08-28 v3 last board last version
    [tn_vdp_v3_board-B_Cu.gbr, tn_vdp_v3_board-B_Mask.gbr, tn_vdp_v3_board-B_Paste.gbr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]
2023-12-02 fix interrupt line as open collector
